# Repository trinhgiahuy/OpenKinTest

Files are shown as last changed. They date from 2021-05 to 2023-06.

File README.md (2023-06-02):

## Paper: **Surrogate Modelling for Oxygen Uptake Prediction Using LSTM Neural Network**

The article can be accessed through [mdpi](https://www.mdpi.com/1424-8220/23/4/2249)

## Test command 

```sh
rosrun vectornav vn200_node _serial_port:=/dev/ttyAMA0 _target_baud:=460800 _binary_data_output_port:=2 _binary_ins_data_output_rate:=400
gdb rosrun vectornav vn200_node _serial_port:=/dev/ttyAMA0 _target_baud:=460800 _binary_data_output_port:=2 _binary_ins_data_output_rate:=400
rostopic echo /vectornav/imugps
rostopic hz /vectornav/imugps
rostopic info /vectornav/imugps
ps aux
sudo killall python
sudo killall screen
sudo killall tee
rostopic echo --filter=m.header.seq%200==0 /vectornav/imugps

```
## Source code for devices measuring in the campaign

## TC219 CPU info

```
Device name	HTC219-720-SPC
Full device name	HTC219-720-SPC.ad.tuni.fi
Processor	Intel(R) Core(TM) i7-6700 CPU @ 3.40GHz   3.41 GHz
Installed RAM	32,0 GB
Device ID	bbbf3aca-47cd-4ad8-9fd0-ad23414388c6
Product ID	00329-00000-00003-AA689
System type	64-bit operating system, x64-based processor
Pen and touch	No pen or touch input is available for this display
```

# Usage

## Matlab instruction

Test repo for matab: `D:\(...BackupDdrive)\(..RA)\....PAVEL\MATLAB-APP\test`

- In matlab folder, create folder name ${subjectID}_out, for example `O1_out`
- The directory should include these files:
  * 2022-XX-XX-XX-XX-XX_s.txt (**sliced** ID's gaitpod file)
  * OXYGAX_marker_XXXX_s.txt(**sliced** ID'oxygen file)
  * `run.m` executable file run the everything
  * `features_OK.m`
  * `velSeg.m`
  * `input_features.m`
  * `trainingPartitions.m`
  
- At the begging `run.mat`, change subjectID and change `sortedInputFeatures` to true if want output input features in ordet (false by default) and run the file
- After about 5 mins it will produce input feature file

This section describes the basic usage of the device

## Connecting the devices
* The Xsens IMU units are currently connected through the USB ports and should be connected before powering the device.
* GPS is connected to the UART pins. The device is enumerated as /dev/ttyAMA0 on RPi and /dev/ttyS4 on minnowboard and uses 57600 baud. This all is configured in the ROS launch files.
* It is recommended that the ethernet cable is plugged to a router which will assign an IP address to the device (unless using 3G), currently the OS has issues if you switch to a different router while the device is powered?
* The device gets time from internet, so logs are dated to 1970 or some other wrong time if no internet connection has been available before starting measurements

## Powering
* The device is powered by the powerbank from the USB connector. The runtime with this seems to be around 3-4 h for RPi and 2,5 h for minnowboard.

## Measurements
* The measurement mode is activated in the boot
* Primary led will flash when time is corrected from interney
* The device will start recording as soon as it loses internet connectivity
* It might take a few minutes to start the measurements, if there are errors with gps or imu. Device will try again until everything works.
* Primary led will flash when making IMU alignment, so IMU should be stationary that time and a bit after.
* It seems, the IMU wont start if it has been stationary for some time (MTw wired), so light shake might be needed before use.
* When recording, primary led will be lit.
* Recording will be stopped once the internet connectivity is restored.
* After being stopped, the files will be uploaded to Google Drive (tutopenkin@gmail.com)

## Shutting down
* The power switch on top can be flipped to give shutdown commands to the unit.
* After flipping the switch and waiting some seconds, the USB cable powering the device can be unplugged.

# Connecting to the device
Standard SSH conenction can be made to the device with ssh:

    ssh ubuntu@[IP]
    Password: ubuntu

For RPi with kinetic user: pi, password: raspberry
For minnowboard user: openkin, password: openkin

# Libraries utilized

ROS Driver for XSens MT/MTi/MTi-G devices.

See: http://ros.org/wiki/ethzasl_xsens_driver

ROS driver for ublox

See: https://github.com/KumarRobotics/ublox

Pozyx Arduino library

See: https://github.com/pozyxLabs/Pozyx-Arduino-library

All are added as subtrees to this repo, so updates can be fetched with commands (from git root):

```
git subtree pull --prefix nodes/ublox https://github.com/KumarRobotics/ublox.git master --squash
```
,

```
git subtree pull --prefix nodes/ethzasl_xsens_driver https://github.com/ethz-asl/ethzasl_xsens_driver.git master --squash
```
and
```
git subtree pull --prefix nodes/pozyx/include/Pozyx-custom-library/ https://github.com/pozyxLabs/Pozyx-Arduino-library.git master --squash
cd nodes/pozyx/ínclude
patch -p0 < pozyx-arduino-to-linux.patch
```

# Motion Fusion

http://msthub.ain.rd.tut.fi/mobilemachines/motion_fusion/blob/master/src/KalmanImu.py

# Script startup
The measurements are started by running ~/openkin/start_script.sh, which in turn calls the main script at ~/openkin/measurement.sh using locks.
The script now starts from /etc/rc.local, with lockfile at /home/ubuntu/measurement.lock and as user ubuntu (or pi or openkin).

# Old documentation...
... can be found in Google Docs with the tutopenkin@gmail.com -account.

# For latest documentation, please look at [doc/](doc/)

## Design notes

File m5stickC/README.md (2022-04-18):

[Arduino IDE environment - M5StickC Plus](https://docs.m5stack.com/en/quick_start/m5stickc_plus/arduino)

[Example demo](https://www.brianmoreau.com/projects/M5StickC_Demo/M5StickC_Demo.php)

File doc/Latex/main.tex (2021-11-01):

\documentclass{report}
\usepackage[utf8]{inputenc}
\usepackage{pdfpages}
\usepackage{hyperref}
\usepackage{graphicx}
\usepackage{float}

\title{Datalogger Documentation}
\graphicspath{{./Images/}}
\author{Huy Trinh }
\date{August 2021}

\begin{document}

\begin{titlepage}
\maketitle
\end{titlepage}

\section{Overview}

The datalogger configuration includes\\
\\\textbf{Raspberry Pi 3 Model B + Vectornav VN200}
\\
\\These can be found through these links
\begin{enumerate}
    \item RPi: \url{https://www.raspberrypi.org/products/raspberry-pi-3-model-b/}
    \item VectorNav
    \begin{enumerate}
        \item[2.1] Quick start manual:\url{https://www.vectornav.com/docs/default-source/datasheets/vn-200-datasheet-rev2.pdf?sfvrsn=e1a7b2a0_10}
        \item[2.2] Complete manual page: \url{https://2w6vmg3m8cv83pn80b2dfi9f-wpengine.netdna-ssl.com/wp-content/uploads/assets/1/7/VN200UserManual_UM004_080514.pdf}
    \end{enumerate}
    \item PoEHat: \url{https://www.raspberrypi.org/products/poe-hat/}
\end{enumerate}
The GNSS/VectorNav connects to the mainboard (Raspberry Pi) through UART serial connection.

\section{Hardware}
\subsection{Circuit}
The USB power input is connected to 5V pins along with GNSS power. GNSS data is connected to UART pins. Power switch is connected between GPIO18 (BCM) and ground, pullup enabled in software. Primary LED (blue) is connected to GPIO24 (BCM), secondary LED (green) is connected to GPIO25 (BCM) and tertiary LED (red) is connected to GPIO10 (BCM). All the LEDs are driven with MOSFETs/NPN-transistors.More detail can found at: \url{https://tinyurl.com/ygbxmabs} 
\begin{figure}[H]
    \centering
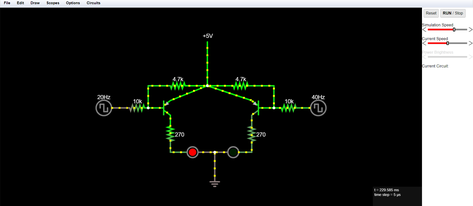
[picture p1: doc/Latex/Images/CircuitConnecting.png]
    
    \caption{CircuitConnecting}
    \label{fig:my_label}
\end{figure}

\subsection{SD Card}
The SD should be 64 GB of space in order to store as much as possible the data collected from the datalogger.\textbf{Remember:} The origin image of the datalogger that we fetch is 32 GB, thus the minimum 32 GB space of SD card is required  
\subsection{USB 3G Modem}
Originally Huawei E160E was used, which works well with 3G speeds. Currently Huawei E3372 4G modem is used (Hi-Link mode). Any modem, which has support on Linux probably can be made to work, some modems can draw more power though, especially LTE modems. On RPi \textbf{max\_usb\_current}=1 setting can be used in \textit{/boot/config.txt}.
\section{Software}
Software can be foud in \url{} repository. Datalogger has accessed to the repo
\subsection{Raspverry Pi Specific}
The raspberry Pi run with operating system Raspbian Jessie with ROS Kinetic Kame, built from source with these instruction \url{http://wiki.ros.org/kinetic/Installation/Source}. More detailed instruction can be found below
\\
\\\textbf{shutdown\_flip.py}:
\\Listens to specific GPIO pin and initiates the shutdown sequence on switch flip
\\
\\\textbf{led-pin.py}:
\\Listen to linux signals USR1 and USR2 to turn led on and off.
\\RPi has one or two pins for HW PWM, but apparently no sysfs interface by default
\\
\\\textbf{led-linuxgpio.sh}:
\\Mainly control the led. Currently, the script is called in measurement script with inverse mode (mode 4). The inverse mode simply reverse the value of variable ON/OFF in its script.
\\
\\\textbf{measurement.sh}
\\The script manage the running nodes nad check if the Internet connection. When the logger is offline, it starts the nodes and logging. When the internet connection is established, the logger uploads the measured data into github/gitlab account.
\\
\\ There are few setting at the beginning of the script, like log files and Leds connected. There are few functions for controlling Leds, currently, we used the led-linuxgpio.sh with inverse mode (mode 4).
\\
\\Function check3G check whether there is \textit{Huawei E160E data stick} is connected, and tries to connect to the internet using \textit{sakis3g-script} (in our case there is not necessary since we are using the \textit{E3372 dongle}).
\\
\\When online for the first time, time is corrected using ntpdate from time1.mikes.fi ntp server and led is blinked fast. When internet is established, it will upload the data into the github/gitlab repository over SSH.
\\
\\\textbf{start\_script.sh}:
\\Start the \textbf{measurement.sh} script using flock. Flockfiles prevent multiple instances of measurement.sh from running at the same time. 

\subsection{Robotic Operating System ROS}
ROS is an open-source, meta-operating system for your robot that providing you with services including hardware abstraction, low-level device control, implementation of commonly-used functionality, message-passing between processes, and package management. It also provides tools and libraries for obtaining, building, writing, and running code across multiple computers. ROS distribution is a versioned set of ROS packages. In our case we use the \textbf{ROS Kinetic Kame} distro.
\subsubsection{VectorNav node}
Highly modified version of \url{https://github.com/dawonn/vectornav}. The data from INS is read over UART at maximum baudrate and then the data is published in custom ROS message (imugps) including necessary fields. THe node also automatically tries to change the baudrate if is not correct. It also includes some configuration for the INS like GPS antenna offset and magnetometer velocity threshold. Also the LED control for turining the LED solid when the GPS fix is acquired.
\subsubsection{ROS Conceptual Terms}
\subsubsection{catkin workspace}
catkin is official build system that combines CMake macros and Python script to provide some functionality on top of  CMake's normal workflow. Catkin is more conventional than \textit{rosbuild} in packages distribution, cross-compiling support and portability. 
\subsubsection{nodes}
Nodes are processes that perform computation. For example, one node controls a laser range-finder, one node controls the wheel motors, one node performs localization, one node performs path planning, one Node provides a graphical view of the system, and so on. A ROS node is written with the use of a ROS client library, such as roscpp or rospy.
\subsubsection{rospy}
rospy is a pure Python client library for ROS. The rospy client API enables Python programmers to quickly interface with ROS Topics, Services, and Parameters.
\subsubsection{topics}
Topics are named buses over which nodes exchange messages. Topics have anonymous publish/subscribe semantics, which decouples the production of information from its consumption. In general, nodes are not aware of who they are communicating with. Instead, nodes that are interested in data subscribe to the relevant topic; nodes that generate data publish to the relevant topic. There can be multiple publishers and subscribers to a topic.
\\We can check our available topic with command \textit{\$ rostopic list} and display messages published to /topic\_name by \textit{\$ rostopic echo /topic\_name}
\subsubsection{messages}
Nodes communicate with each other by publishing the \textbf{messages} to topics. A message is a simple data structure comprise the specific fields.
\begin{itemize}
    \item \textbf{msg files}: are simple text files for specifying the data structure of a message. These files are stored in the msg subdirectory of a package. For more information about these files, including a type specification, see the \textit{\href{https://wiki.ros.org/msg}{\underline{msg format}}}.
    \item \textbf{msg types}: are understand of ROS \textit{\href{https://wiki.ros.org/Names}{\underline{naming}}} convention: the name of package + / + name of .msg file. For instance, the \textit{std\_msgs/msg/String.msg} has the message type \textit{std\_msgs/String}
    \item \textbf{building}: ROS \textit{\href{http://wiki.ros.org/Client\%20Libraries} {\underline{Client Libraries}}} implement a message generator that translate .msg file into source code.
    The generator must be invoked from your build script by adding the line
    \textbf{\textit{rosbuild\_genmsg()}} to your
    \href{https://wiki.ros.org/action/show/rosbuild/CMakeLists?action=show&redirect=CMakeLists}{\underline{CMakeList.txt}}
    \item \textbf{header}: A msg may include a special message type called 'Header', which include some common metadata field such as timestamp and frame ID.
    \begin{figure}[H]
        \centering
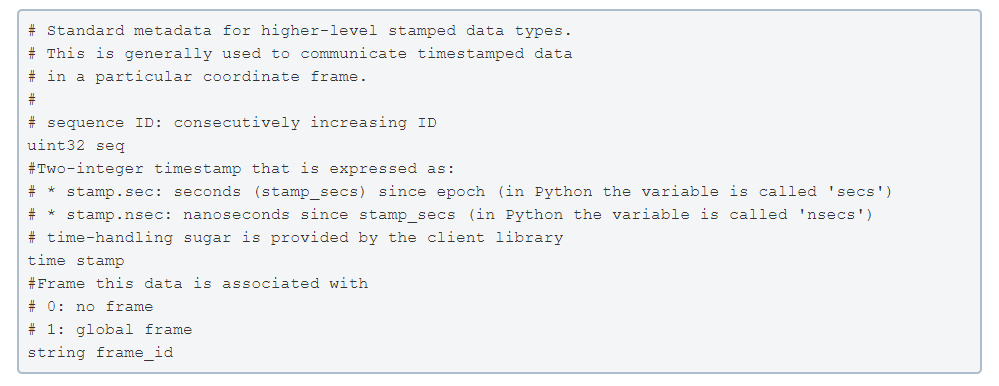
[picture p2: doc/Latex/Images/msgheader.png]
        
        \caption{Message Header}
        \label{fig:my_label}
    \end{figure}
\end{itemize}
\subsubsection{bags}
Bags are a format for saving and playing back ROS message data. Bags are an important mechanism for storing data, such as sensor data, that can be difficult to collect but is necessary for developing and testing algorithms.
\subsubsection{package}
\href{http://wiki.ros.org/Packages}{Packages} might contain ROS nodes, ROS-independent library, a dataset, configuration files, a third-party software. Packages are created by hand or with tools like \textbf{catkin\_create\_pkg}. ROS package is a directory desended from \textit{ROS\_PACKAGE\_PATH} in \textit{\href{http://wiki.ros.org/ROS/EnvironmentVariables}{\underline{ROS Environment variable}}} that has a \href{http://wiki.ros.org/Manifest}{\textit{package.xml}} file in it.\\
ROS packages commonly contain the following strucutes.
\begin{itemize} 
    \item \textit{include/package\_name}: C++ incude header (make sure it export in CMakeLists.txt) 
    \item \textit{msg}/: folder contain Message(msg) types
    \item \textit{src/package\_name/}: source file, especially Python source that are exported to other packages
    
    %Do not know why if we use \textit here will cause error of `undefined control sequence` but change to \emph get rid of it
    \item \emph{scripts/}: executabe scripts
    \item \emph{CMakeList.txt}: CMake build file
    \item \emph{package.xml}: Package
    \underline{\href{http://wiki.ros.org/catkin/CMakeLists.txt}{catkin/CMakeLists.txt}}
\end{itemize}
There are few tools that help to manage the packages
\begin{itemize}
    \item \textit{rospack}: find and retrieve information about packet
    \item \textit{catkin\_create\_package}: create a new package
    \item \textit{catkin\_make}: build a workspace of package
    \item \textit{rosdep}: install system dependencies of a package
\end{itemize}
\subsubsection{catkin\_make}
A convenience tool for buidling code in workspace. Here we use\\
\textbf{\emph{\$ cd \~/catkin\_ws}}\\
\textbf{\emph{\$ catkin\_make}}\\
to compile and build our workspace. After running \emph{\textbf{catkin\_make}} we have 2 folder \emph{build} and \emph{devel} in our root of catkin workspace. The \emph{build} folder is where \emph{cmake} and \emph{make} are invoke, and the devel folder contains any generated files and targets, plus setup *.sh file so that you can use it like it is installed.

\subsubsection{package.xml}
A \textbf{package manifest} XML file that must be included with any catkin-compliant package's root folder that defines that package's properties such as package name, version number, author, maintainers and dependencies on other catkin package.\\
Some required tags include\\
\begin{itemize}
% Why <> cannot be compiled?
    \item \textit{name}: <name> of package
    \item \emph{<version>}: version of package
    \item \emph{<description>}: description of package content
    \item \emph{<maintainer>}: the name of person(s) that is/are maintaining the package
    \item \emph{<license>}: software license(s) (e.g GPL,BSD,ASL) under which code is release 
\end{itemize}

\subsection{Installing software}
First, operating system should be installed, for example (L)Ubuntu 16.04 minimal. Instructions can be found on Ubuntu website, for example: \url{https://help.ubuntu.com/community/Lubuntu/Documentation/MinimalInstall}. 
\\
Instructions for installing ROS can be found in \url{http://wiki.ros.org/kinetic/Installation/}.\\
Brief list of commands:
*adjust usernames etc. according to the local user, here openkin or pi*\\
\\
\# For raspbian jessie source installation: \# enough swap for build to succeed \\
\\
sudo fallocate -l 2G /var/swap2 \\ 
\\
sudo chmod 600 /var/swap2 \\
\\
sudo swapon /var/swap2 \\
\\
sudo sh -c 'echo "deb http://packages.ros.org/ros/ubuntu \$(lsb\_release -sc) main" > /etc/apt/sources.list.d/ros-latest.list' \\
\\
sudo apt-key adv --keyserver 'hkp://keyserver.ubuntu.com:80' --recv-keyC1CF6E31E6BADE8868B172B4F42ED6FBAB17C654 \\
\\
sudo apt-key del 421C365BD9FF1F717815A3895523BAEEB01FA116 \\
\\
sudo apt-get install python-rosdep python-rosinstall-generator python-wstool python-rosinstall build-essential git libgps-dev i2c-tools libi2c-dev \\
\\
sudo rosdep init \\
\\
rosdep uodate \\
\\
cd \\ 
\\
mkdir ros\_catkin\_ws \\
\\
cd ros\_catkin\_ws \\
\\
rosinstall\_generator ros\_comm --rosdistro kinetic --deps --wet-only --tar > kinetic-ros\_comm-wet.rosinstall \\
\\
roslocate info common\_msgs --distro=kinetic >> kinetic-ros\_comm-wet.rosinstall \\
\\
roslocate info tf --distro=kinetic >> kinetic-ros\_comm-wet.rosinstall \\
\\
roslocate info tf2 --distro=kinetic >> kinetic-ros\_comm-wet.rosinstall \\
\\
roslocate info diagnostic\_updater --distro=kinetic >> kinetic-ros\_comm-wet.rosinstall \\
\\
roslocate info actionlib --distro=kinetic >> kinetic-ros\_comm-wet.rosinstall \\
\\
roslocate info python\_orocos\_kdl --distro=kinetic >> kinetic-ros\_comm-wet.rosinstall \\
\\
roslocate info bondcpp --distro=kinetic >> kinetic-ros\_comm-wet.rosinstall \\
\\
nano kinetic-ros\_comm-wet.rosinstall \\
\\
\textbf{\emph{add to the end of file: - git: local-name:}} \\
\\
rosbag\_migration\_rule uri: \\
https://github.com/ros/rosbag\_migration\_rule.git\\
version: master \\
\*
\\
roslocate info pluginlib --distro=kinetic >> kinetic-ros\_comm-wet.rosinstall \\
\\
roslocate info angles --distro=kinetic >> kinetic-ros\_comm-wet.rosinstall \\
\\
roslocate info class\_loader --distro=kinetic >> kinetic-ros\_comm-wet.rosinstall \\
\\
wstool init -j4 src kinetic-ros\_comm-wet.rosinstall \\
\\
(sudo cp /usr/share/cmake-3.0/Modules/FindEigen3.cmake /usr/share/cmake-3.6/Modules/) \\
\\
rosdep install --from-paths src --ignore-src --rosdistro kinetic -y \\
\\
sudo mkdir -p /opt/ros/kinetic \\
\\
sudo chmod -R 777 /opt/ros \\
\\
sudo chown -R pi:pi /opt/ros \\
\\
./src/catkin/bin/catkin\_make\_isolated --install --install-space /opt/ros/kinetic -DCMAKE\_BUILD\_TYPE=Release \\
\\
cd\\
\\
\# Normal ubuntu, skip if from source\\
\\
The complete image of Ubuntu 16-04 with ROS kinetic already installed for raspberry pi 3 can be found at \url{https://ubiquity-pi-image.sfo2.cdn.digitaloceanspaces.com/2020-11-07-ubiquity-xenial-lxde-raspberry-pi.img.xz}\\
\\
sudo sh -c 'echo "deb http://packages.ros.org/ros/ubuntu \$(lsb\_release -sc) main" > /etc/apt/sources.list.d/ros-latest.list' 
\\
sudo apt-key adv --keyserver 'hkp://keyserver.ubuntu.com:80' --recv-keyC1CF6E31E6BADE8868B172B4F42ED6FBAB17C654 \\
\\
sudo apt-key del 421C365BD9FF1F717815A3895523BAEEB01FA116 \\
\\
sudo apt-get update\\
\\
rosdep update\\
\\
source ~/.bashrc\\
\\
sudo apt-get install libgps-dev libi2c-dev ntpdate\\
\\
sudo apt-get upgrade\\
\\
\\
\# Same for here\\
\\
% Not need to init catkin workspace anymore
catkin\_make\\
\\
source devel/setup.bash\\
\\
\textbf{\#If you start from here with fetching from the complete datalogger image}\\
\\
cd catkin\_ws/src\\
\\
ln -s /home/openkin/openkin/nodes/ascii\_logger/ascii\_logger\\
\\
ln -s /home/openkin/NewGaitMaven/nodes/vectornav vectornav \\
\\
\# for rpi \\
\\cd\\
\\
wget https://github.com/joan2937/pigpio/archive/master.zip\\
\\
unzip master.zip \\
\\
cd pigpio-master \\
\\
make -j4 \\
\\
sudo make install\\
\\
cd ~/catkin\_ws \\
\\
catkin\_make\\
\\
sudo visudo \\
\\
\textbf{*add line at the end: “openkin ALL=(ALL:ALL) NOPASSWD: ALL”*}\\
\\
sudo apt-get install screen ppp usb-modeswitch\\
\\
\textbf{\#if using E160E or similar }\\
\\
wget http://www.sakis3g.com/downloads/sakis3g.tar.gz\\
\\
tar -xzvf sakis3g.tar.gz\\
\\
sudo mv sakis3g /usr/bin/sakis3g \\
\\
sudo chown root:root /usr/bin/sakis3g\\
\\
sudo chmod +x /usr/bin/sakis3g \\
\\
\textbf{*if e3372 doesn’t work out of the box*}\\
\\
\textbf{*remove old usb\_modeswitch*}\\
\\
\textbf{*install tcl, libusb-1.0-0-dev etc.*}\\
\\
\textbf{*download latest usb\_modeswitch http://www.draisberghof.de/usb\_modeswitch/\#install*}\\
\\
\textbf{*sudo make install*}\\
\\
\\
\\
\textbf{Here we start to install git lfs for data storage}
% Add install golang and gitlfs
\\
\\
\\
cd \~/openkin/NewGaitMaven/linux-shutdown\\
\\
make\\
\\
\\
\\
% Enable automatic measurement
sudo nano /etc/rc.local\\
\\
\textbf{*add line before exit 0:}\\
\textit{“su -c “/home/openkin/NewGaitMaven/start\_script.sh” openkin}\\
\\
\textbf{*for rpi add shutdown\_flip*}\\
\\
\textbf{*check permissions for serial device, pi: /boot/cmdline.txt: remove serial terminal*}\\
\\
\textbf{*add source’s to .bashrc*}\\
\\
\textbf{*check usernames and folders in measurement.sh*}\\
\\
\\
\\
\# \textbf{For mtmanager}\\
\\
sudo apt-get install libqtopengl5 \\
\\
\textbf{*download mtmanager, extract, symlink to /usr/local/bin *}\\
\\
\subsection{3D Printed Cases}
Models can be found in 3D folder. They can be redesigned with SolidWork/FreeCad. FreeCad can be download for free. However, SolidWork require license from university and can be installed from IT-helpdesk.
\textbf{Some information and settings for printers} \\
Get start by running the script 
C:$\backslash$Minifactory$\backslash$Config$\backslash$first\_time\_config.bat.
Then press any key to continue\\
\\
Open Minifactory\\
\textbf{Step 1}: Start connect Z-calibration\\
\textbf{Step 2}: Run the nozzle up/down by pressing the arrow button until the paper slightly rubs between the nozzle and the print bed. Confirm height with “Ready” button. The height should be around 150cm\\
In manual control tab, uncheck the flowrate, bed temperature, extruder 1, extruder 2,. We mostly use extruder 1 for printing, the temperature is around 200 degree celsius.  

In object placement, add object and rotate it that its suitable (not need to much support )
In slicer tab, choose Slicer as Slic 3r or CuraEngine (prefered). If CuraEngine, the quality should be 0.2 mm and support everywhere.. The Filament setting is PLA for both extruder.

The preview tab can show each layer in real-time printing. Also, it shows the estimated print time, layer counts. Finally press Start Print.

\section{Usage}
\subsection{VectorNav}
The datalogger is off, if light is not on. The 4G modem should also be connected to the USB port before turning the logger on. The logger can be turn on by pressing the power button on the battery, inserting the battery to the case and connecting USB-cable to the battery. The logger will turn on and off the red and green leds when powering up respectively. When the logger acquire the internet connection, the green led is turned on. When the logger is synchronizing github/gitlab server, the green led is flashing\\
\\
When the logger has been on for a while and the green led is on, the logger is ready for starting measurement. The measurement can be started by disconnecting the 4G modem. 
The green led goes off and after a while, the red should start blinking if the VectorNav does not have fix, or if everything seem to be fine, the red led is turned on. It is still recommend to wait for GPS to acquire better stability, but the recording is running.\\
\\
When measurement are done, the recording can be stopped by reconnecting the 4G modem. The red led shuts off and the green led starts to blink as files are upload to github/gitlab. When the upload is done, the green led stabilize.\\
\\
The logger can be turn off by turning the power/shutdown switch off, and waiting for 10-30 seconds for all lights to go off. When logger is off, the USB power cable can be disconnected with care, and battery removed.\\
\\
Note: JYU version has reverse switch direction compared to other loggers, on is out, off is towards the antenna.

\section{SSH access}
The datalogger have SSH server running, and they can be accessed by connecting the datalogger via ethernet. The network should have DHCP to give IP address for the datalogger. For example internet sharing on Mac and Linux can be used for connecting the datalogger straight to the computer.\\
\\
The IP of the datalogger can possibly found using \textit{nmap}: \textit{nmap -sn 192.168.2.1-255} where IP range is subnet defined for network. The SSH connection can be mad with command \textit{ssh pi$@$192.168.2.3} where IP is the IP of the datalogger, and pi is the username.\\
\\
Username for Raspberry Pi based datalogger is pi. Password is raspberry for pi and openkin for openkin.\\
\\
\end{document}

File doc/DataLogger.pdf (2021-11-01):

# Datalogger Documentation

Huy Trinh

August 2021

## 0.1 Overview

The datalogger configuration includes

Raspberry Pi 3 Model B + Vectornav VN200

These can be found through these links

1. RPi: https://www.raspberrypi.org/products/raspberry-pi-3-model-b/
2. VectorNav

2.1 Quick start manual:https://www.vectornav.com/docs/default-source/datasheets/vn-200-datasheet-rev2.pdf?sfvrsn=e1a7b2a0_10 (https://www.vectornav.com/docs/default-source/datasheets/vn-200-datasheet-rev2.pdf?sfvrsn=e1a7b2a0_10)

2.2 Complete manual page: https://2w6vmg3m8cv83pn80b2dfi9f-wpengine.netdna-ssl.com/wp-content/uploads/assets/1/7/VN200UserManual_UM004_080514.pdf (https://2w6vmg3m8cv83pn80b2dfi9f-wpengine.netdna-ssl.com/wp-content/uploads/assets/1/7/VN200UserManual_UM004_080514.pdf)

3. PoEHat: https://www.raspberrypi.org/products/poe-hat/

The GNSS/VectorNav connects to the mainboard (Raspberry Pi) through UART serial connection.

## 0.2 Hardware

### 0.2.1 Circuit

The USB power input is connected to 5V pins along with GNSS power. GNSS data is connected to UART pins. Power switch is connected between GPIO18 (BCM) and ground, pullup enabled in software. Primary LED (blue) is connected to GPIO24 (BCM), secondary LED (green) is connected to GPIO25 (BCM) and tertiary LED (red) is connected to GPIO10 (BCM). All the LEDs are driven with MOSFETs/NPN-transistors.More detail can found at: https: //tinyurl.com/ygbxmabs

1

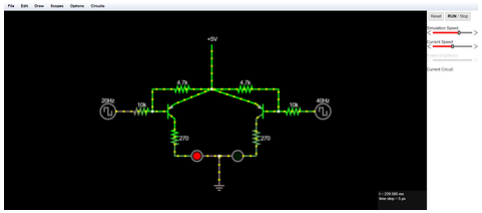
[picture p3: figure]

Figure 1: CircuitConnecting

### 0.2.2 SD Card

The SD should be 64 GB of space in order to store as much as possible the data collected from the datalogger.Remember: The origin image of the datalogger that we fetch is 32 GB, thus the minimum 32 GB space of SD card is required

### 0.2.3 USB 3G Modem

Originally Huawei E160E was used, which works well with 3G speeds. Currently Huawei E3372 4G modem is used (Hi-Link mode). Any modem, which has support on Linux probably can be made to work, some modems can draw more power though, especially LTE modems. On RPi max usb current=1 setting can be used in /boot/config.txt.

## 0.3 Software

Software can be foud in repository. Datalogger has accessed to the repo

### 0.3.1 Raspverry Pi Specific

The raspberry Pi run with operating system Raspbian Jessie with ROS Kinetic Kame, built from source with these instruction http://wiki.ros.org/kinetic/Installation/Source. (http://wiki.ros.org/kinetic/Installation/Source) More detailed instruction can be found below

shutdown flip.py:
Listens to specific GPIO pin and initiates the shutdown sequence on switch flip

led-pin.py:
Listen to linux signals USR1 and USR2 to turn led on and off.

2

RPi has one or two pins for HW PWM, but apparently no sysfs interface by default

led-linuxgpio.sh:
Mainly control the led. Currently, the script is called in measurement script with inverse mode (mode 4). The inverse mode simply reverse the value of variable ON/OFF in its script.

measurement.sh
The script manage the running nodes nad check if the Internet connection. When the logger is offline, it starts the nodes and logging. When the internet connection is established, the logger uploads the measured data into github/gitlab account.

There are few setting at the beginning of the script, like log files and Leds connected. There are few functions for controlling Leds, currently, we used the led-linuxgpio.sh with inverse mode (mode 4).

Function check3G check whether there is Huawei E160E data stick is connected, and tries to connect to the internet using sakis3g-script (in our case there is not necessary since we are using the E3372 dongle).

When online for the first time, time is corrected using ntpdate from time1.mikes.fi ntp server and led is blinked fast. When internet is established, it will upload the data into the github/gitlab repository over SSH.

start script.sh:
Start the measurement.sh script using flock. Flockfiles prevent multiple instances of measurement.sh from running at the same time.

### 0.3.2 Robotic Operating System ROS

ROS is an open-source, meta-operating system for your robot that providing you with services including hardware abstraction, low-level device control, implementation of commonly-used functionality, message-passing between processes, and package management. It also provides tools and libraries for obtaining, building, writing, and running code across multiple computers. ROS distribution is a versioned set of ROS packages. In our case we use the ROS Kinetic Kame distro.

VectorNav node

Highly modified version of https://github.com/dawonn/vectornav. The data from INS is read over UART at maximum baudrate and then the data is published in custom ROS message (imugps) including necessary fields. THe node also automatically tries to change the baudrate if is not correct. It also includes

3

some configuration for the INS like GPS antenna offset and magnetometer velocity threshold. Also the LED control for turining the LED solid when the GPS fix is acquired.

ROS Conceptual Terms

catkin workspace

catkin is official build system that combines CMake macros and Python script to provide some functionality on top of CMake’s normal workflow. Catkin is more conventional than rosbuild in packages distribution, cross-compiling support and portability.

nodes

Nodes are processes that perform computation. For example, one node controls a laser range-finder, one node controls the wheel motors, one node performs localization, one node performs path planning, one Node provides a graphical view of the system, and so on. A ROS node is written with the use of a ROS client library, such as roscpp or rospy.

rospy

rospy is a pure Python client library for ROS. The rospy client API enables Python programmers to quickly interface with ROS Topics, Services, and Parameters.

topics

Topics are named buses over which nodes exchange messages. Topics have anonymous publish/subscribe semantics, which decouples the production of information from its consumption. In general, nodes are not aware of who they are communicating with. Instead, nodes that are interested in data subscribe to the relevant topic; nodes that generate data publish to the relevant topic. There can be multiple publishers and subscribers to a topic.
We can check our available topic with command $ rostopic list and display messages published to /topic name by $ rostopic echo /topic name

messages

Nodes communicate with each other by publishing the messages to topics. A message is a simple data structure comprise the specific fields.

- msg files: are simple text files for specifying the data structure of a message. These files are stored in the msg subdirectory of a package. For more information about these files, including a type specification, see the msg format. (https://wiki.ros.org/msg)

4

- msg types: are understand of ROS naming (https://wiki.ros.org/Names) convention: the name of package + / + name of .msg file. For instance, the std msgs/msg/String.msg has the message type std msgs/String
- building: ROS Client Libraries (http://wiki.ros.org/Client%20Libraries) implement a message generator that translate .msg file into source code. The generator must be invoked from your build script by adding the line rosbuild genmsg() to your CMakeList.txt (https://wiki.ros.org/action/show/rosbuild/CMakeLists?action=show&redirect=CMakeLists)
- header: A msg may include a special message type called ’Header’, which include some common metadata field such as timestamp and frame ID.


Figure 2: Message Header

bags

Bags are a format for saving and playing back ROS message data. Bags are an important mechanism for storing data, such as sensor data, that can be difficult to collect but is necessary for developing and testing algorithms.

package

Packages (http://wiki.ros.org/Packages) might contain ROS nodes, ROS-independent library, a dataset, configuration files, a third-party software. Packages are created by hand or with tools like catkin create pkg. ROS package is a directory desended from ROS PACKAGE PATH in ROS Environment variable (http://wiki.ros.org/ROS/EnvironmentVariables) that has a package.xml (http://wiki.ros.org/Manifest) file in it.
ROS packages commonly contain the following strucutes.
- include/package name: C++ incude header (make sure it export in CMake-Lists.txt)
- msg/: folder contain Message(msg) types
- src/package name/ : source file, especially Python source that are exported to other packages

5

- scripts/ : executabe scripts
- CMakeList.txt: CMake build file
- package.xml: Package catkin/CMakeLists.txt (http://wiki.ros.org/catkin/CMakeLists.txt)

There are few tools that help to manage the packages

- rospack: find and retrieve information about packet
- catkin create package: create a new package
- catkin make: build a workspace of package
- rosdep: install system dependencies of a package

catkin make

A convenience tool for buidling code in workspace. Here we use
$ cd ˜/catkin ws
$ catkin make
to compile and build our workspace. After running catkin make we have 2 folder build and devel in our root of catkin workspace. The build folder is where cmake and make are invoke, and the devel folder contains any generated files and targets, plus setup *.sh file so that you can use it like it is installed.

package.xml

A package manifest XML file that must be included with any catkin-compliant package’s root folder that defines that package’s properties such as package name, version number, author, maintainers and dependencies on other catkin package.
Some required tags include
- name: ¡name¿ of package
- ¡version¿: version of package
- ¡description¿: description of package content
- ¡maintainer¿: the name of person(s) that is/are maintaining the package
- ¡license¿: software license(s) (e.g GPL,BSD,ASL) under which code is release

6

### 0.3.3 Installing software

First, operating system should be installed, for example (L)Ubuntu 16.04 minimal. Instructions can be found on Ubuntu website, for example: https: //help.ubuntu.com/community/Lubuntu/Documentation/MinimalInstall. Instructions for installing ROS can be found in http://wiki.ros.org/kinetic/Installation/. (http://wiki.ros.org/kinetic/Installation/)
Brief list of commands: *adjust usernames etc. according to the local user, here openkin or pi*

# For raspbian jessie source installation: # enough swap for build to succeed

sudo fallocate -l 2G /var/swap2

sudo chmod 600 /var/swap2

sudo swapon /var/swap2

sudo sh -c ’echo ”deb http://packages.ros.org/ros/ubuntu $(lsb release -sc) main”
¿ /etc/apt/sources.list.d/ros-latest.list’

sudo apt-key adv –keyserver ’hkp://keyserver.ubuntu.com:80’ –recv-keyC1CF6E31E6BADE8868B172B4F42ED6FBAB17C654

sudo apt-key del 421C365BD9FF1F717815A3895523BAEEB01FA116

sudo apt-get install python-rosdep python-rosinstall-generator python-wstool python-rosinstall build-essential git libgps-dev i2c-tools libi2c-dev

sudo rosdep init

rosdep uodate

cd

mkdir ros catkin ws

cd ros catkin ws

rosinstall generator ros comm –rosdistro kinetic –deps –wet-only –tar ¿ kinetic-ros comm-wet.rosinstall

roslocate info common msgs –distro=kinetic ¿¿ kinetic-ros comm-wet.rosinstall

roslocate info tf –distro=kinetic ¿¿ kinetic-ros comm-wet.rosinstall

roslocate info tf2 –distro=kinetic ¿¿ kinetic-ros comm-wet.rosinstall

7

roslocate info diagnostic updater –distro=kinetic ¿¿ kinetic-ros comm-wet.rosinstall

roslocate info actionlib –distro=kinetic ¿¿ kinetic-ros comm-wet.rosinstall

roslocate info python orocos kdl –distro=kinetic ¿¿ kinetic-ros comm-wet.rosinstall

roslocate info bondcpp –distro=kinetic ¿¿ kinetic-ros comm-wet.rosinstall

nano kinetic-ros comm-wet.rosinstall

add to the end of file: - git: local-name:

rosbag migration rule uri: https://github.com/ros/rosbag migration rule.git
version: master

roslocate info pluginlib –distro=kinetic ¿¿ kinetic-ros comm-wet.rosinstall

roslocate info angles –distro=kinetic ¿¿ kinetic-ros comm-wet.rosinstall

roslocate info class loader –distro=kinetic ¿¿ kinetic-ros comm-wet.rosinstall

wstool init -j4 src kinetic-ros comm-wet.rosinstall

(sudo cp /usr/share/cmake-3.0/Modules/FindEigen3.cmake /usr/share/cmake-3.6/Modules/)

rosdep install –from-paths src –ignore-src –rosdistro kinetic -y

sudo mkdir -p /opt/ros/kinetic

sudo chmod -R 777 /opt/ros

sudo chown -R pi:pi /opt/ros

./src/catkin/bin/catkin make isolated –install –install-space /opt/ros/kinetic -DCMAKE BUILD TYPE=Release

cd

# Normal ubuntu, skip if from source

The complete image of Ubuntu 16-04 with ROS kinetic already installed for raspberry pi 3 can be found at https://ubiquity-pi-image.sfo2.cdn.digitaloceanspaces.com/2020-11-07-ubiquity-xenial-lxde-raspberry-pi.img.xz (https://ubiquity-pi-image.sfo2.cdn.digitaloceanspaces.com/2020-11-07-ubiquity-xenial-lxde-raspberry-pi.img.xz)

8

sudo sh -c ’echo ”deb http://packages.ros.org/ros/ubuntu $(lsb release -sc) main”
¿ /etc/apt/sources.list.d/ros-latest.list’
sudo apt-key adv –keyserver ’hkp://keyserver.ubuntu.com:80’ –recv-keyC1CF6E31E6BADE8868B172B4F42ED6FBAB17C654

sudo apt-key del 421C365BD9FF1F717815A3895523BAEEB01FA116

sudo apt-get update

rosdep update

source /.bashrc

sudo apt-get install libgps-dev libi2c-dev ntpdate

sudo apt-get upgrade

# Same for here

catkin make

source devel/setup.bash

#If you start from here with fetching from the complete datalogger image

cd catkin ws/src

ln -s /home/openkin/openkin/nodes/ascii logger/ascii logger

ln -s /home/openkin/NewGaitMaven/nodes/vectornav vectornav

# for rpi

cd

wget https://github.com/joan2937/pigpio/archive/master.zip

unzip master.zip

cd pigpio-master

make -j4

sudo make install

9

cd /catkin ws

catkin make

sudo visudo

*add line at the end: “openkin ALL=(ALL:ALL) NOPASSWD: ALL”*

sudo apt-get install screen ppp usb-modeswitch

#if using E160E or similar

wget http://www.sakis3g.com/downloads/sakis3g.tar.gz

tar -xzvf sakis3g.tar.gz

sudo mv sakis3g /usr/bin/sakis3g

sudo chown root:root /usr/bin/sakis3g

sudo chmod +x /usr/bin/sakis3g

*if e3372 doesn’t work out of the box*

*remove old usb modeswitch*

*install tcl, libusb-1.0-0-dev etc.*

*download latest usb modeswitch http://www.draisberghof.de/usb modeswitch/#install*

*sudo make install*

Here we start to install git lfs for data storage

cd ˜/openkin/NewGaitMaven/linux-shutdown

make

sudo nano /etc/rc.local

10

*add line before exit 0:
“su -c “/home/openkin/NewGaitMaven/start script.sh” openkin

*for rpi add shutdown flip*

*check permissions for serial device, pi: /boot/cmdline.txt: remove serial terminal*

*add source’s to .bashrc*

*check usernames and folders in measurement.sh*

# For mtmanager

sudo apt-get install libqtopengl5

*download mtmanager, extract, symlink to /usr/local/bin *

0.3.4 3D Printed Cases

Models can be found in 3D folder. They can be redesigned with SolidWork/FreeCad. FreeCad can be download for free. However, SolidWork require license from university and can be installed from IT-helpdesk. Some information and settings for printers
Get start by running the script C:\Minifactory\Config\first time config.bat. Then press any key to continue

Open Minifactory
Step 1: Start connect Z-calibration
Step 2: Run the nozzle up/down by pressing the arrow button until the paper slightly rubs between the nozzle and the print bed. Confirm height with “Ready” button. The height should be around 150cm
In manual control tab, uncheck the flowrate, bed temperature, extruder 1, extruder 2,. We mostly use extruder 1 for printing, the temperature is around 200 degree celsius.
In object placement, add object and rotate it that its suitable (not need to much support ) In slicer tab, choose Slicer as Slic 3r or CuraEngine (prefered). If CuraEngine, the quality should be 0.2 mm and support everywhere.. The Filament setting is PLA for both extruder.
The preview tab can show each layer in real-time printing. Also, it shows the estimated print time, layer counts. Finally press Start Print.

11

## 0.4 Usage

### 0.4.1 VectorNav

The datalogger is off, if light is not on. The 4G modem should also be connected to the USB port before turning the logger on. The logger can be turn on by pressing the power button on the battery, inserting the battery to the case and connecting USB-cable to the battery. The logger will turn on and off the red and green leds when powering up respectively. When the logger acquire the internet connection, the green led is turned on. When the logger is synchronizing github/gitlab server, the green led is flashing

When the logger has been on for a while and the green led is on, the logger is ready for starting measurement. The measurement can be started by disconnecting the 4G modem. The green led goes off and after a while, the red should start blinking if the VectorNav does not have fix, or if everything seem to be fine, the red led is turned on. It is still recommend to wait for GPS to acquire better stability, but the recording is running.

When measurement are done, the recording can be stopped by reconnecting the 4G modem. The red led shuts off and the green led starts to blink as files are upload to github/gitlab. When the upload is done, the green led stabilize.

The logger can be turn off by turning the power/shutdown switch off, and waiting for 10-30 seconds for all lights to go off. When logger is off, the USB power cable can be disconnected with care, and battery removed.

Note: JYU version has reverse switch direction compared to other loggers, on is out, off is towards the antenna.

## 0.5 SSH access

The datalogger have SSH server running, and they can be accessed by connecting the datalogger via ethernet. The network should have DHCP to give IP address for the datalogger. For example internet sharing on Mac and Linux can be used for connecting the datalogger straight to the computer.

The IP of the datalogger can possibly found using nmap: nmap -sn 192.168.2.1-255 where IP range is subnet defined for network. The SSH connection can be mad with command ssh pi@192.168.2.3 where IP is the IP of the datalogger, and pi is the username.

Username for Raspberry Pi based datalogger is pi. Password is raspberry for pi and openkin for openkin.

12

13

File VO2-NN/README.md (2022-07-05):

## NORE: SUBJECT 2 HERE MEANS SUBJECT 3

### EvaluateTable

| ModelName 								 | Pred1					 	|Pred2	 			 | 
|---|---|
|Best_nha_bao_model_bidir.h5			 | |0.3535 |
|ModelTrained-12									 |0. 			| |
|ModelTrained-121 | |0.2020 |

Some important link

[Normalize columns of pandas data frame](https://stackoverflow.com/questions/26414913/normalize-columns-of-pandas-data-frame)

[Solving TensorFlow cuDNN Initialization Failure Problem](https://leimao.github.io/blog/TensorFlow-cuDNN-Failure/)

It has been a few times that I ran into the following error when I was using TensorFlow in the Docker container.

```
Unknown: Failed to get convolution algorithm. This is probably because cuDNN failed to initialize, so try looking to see if a warning log message was printed above.
```
It seems that it is because cuDNN failed to initialize. However, the reasons behind causing this are unknown.

Usually restarting the computer would solve the problem. However, if we don’t want to spend time restarting the computer, there are some quick solutions.

## TensorFlow-Keras 1.x

```
config = tf.ConfigProto()
config.gpu_options.allow_growth = True
tf.keras.backend.set_session(tf.Session(config=config))
```

## TensorFlow 2.x

```
gpu_devices = tf.config.experimental.list_physical_devices('GPU')
for device in gpu_devices:
    tf.config.experimental.set_memory_growth(device, True)
```

## TensorFlow Allow Growth

By default, TensorFlow would use all the GPU memory regardless of the size of the model you are running. 

That is also why we would need to specify the visible GPU devices when we are running the model on a multi-GPU server to prevent collisions with others. To only use the memory required for the model, we set the GPU memory to allow growth.

But it still remains mysterious to me why cuDNN sometimes would fail to initialize if the GPU memory does not allow growth.

## References

[TensorFlow 1.x Bug](https://github.com/tensorflow/tensorflow/issues/24828)

[keras LSTM Fail to find the dnn implementation #36508](https://github.com/tensorflow/tensorflow/issues/36508)

[TensorFlow 2.x - Limiting GPU Memory Growth](https://www.tensorflow.org/guide/gpu#limiting_gpu_memory_growth)

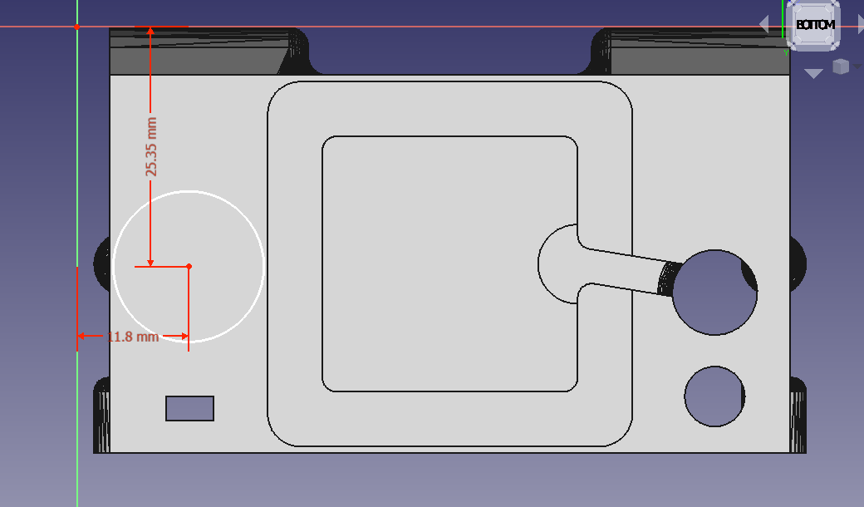
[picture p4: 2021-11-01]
3d/MyFirstDataLoggerCase/blockbase_design_number_4.png

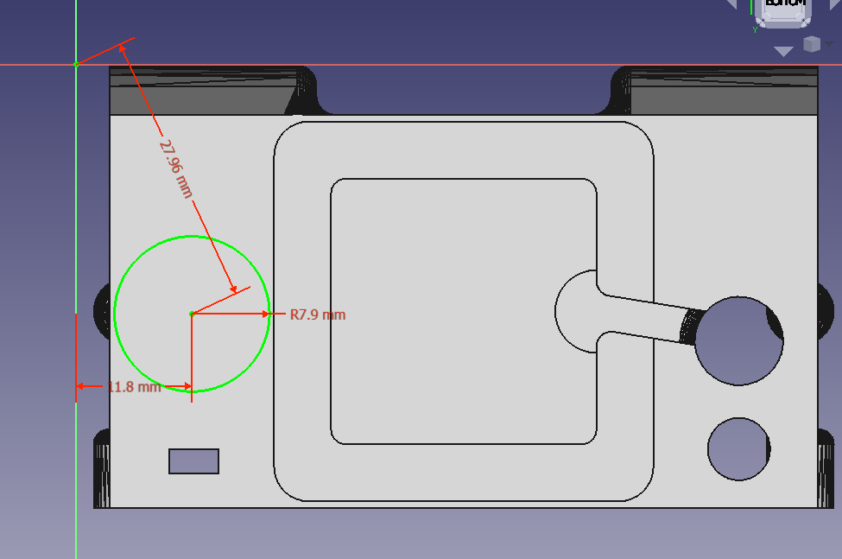
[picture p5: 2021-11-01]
3d/MyFirstDataLoggerCase/blockbase_design_number_3.png

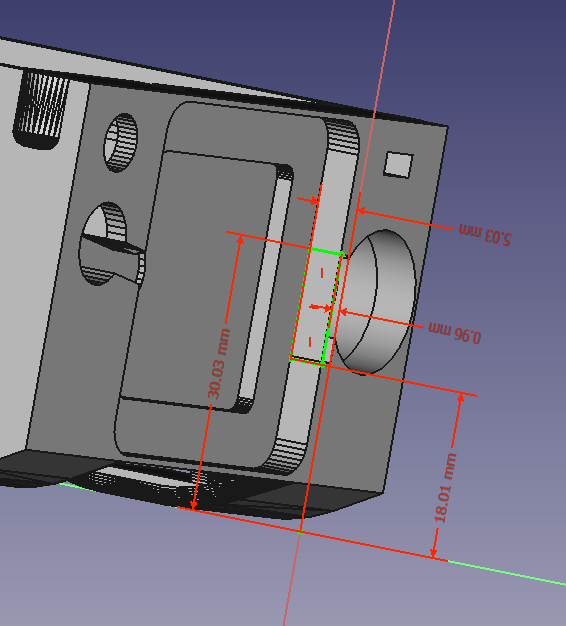
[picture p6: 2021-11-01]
3d/MyFirstDataLoggerCase/blockbase_design_number_1.png

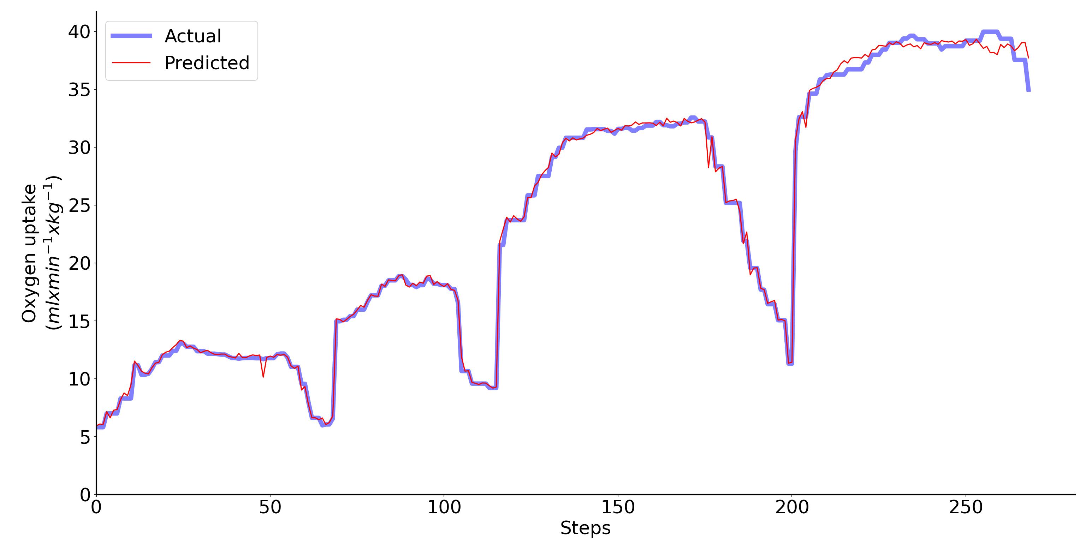
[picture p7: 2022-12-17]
paperSource/withHR_Subj9.jpg

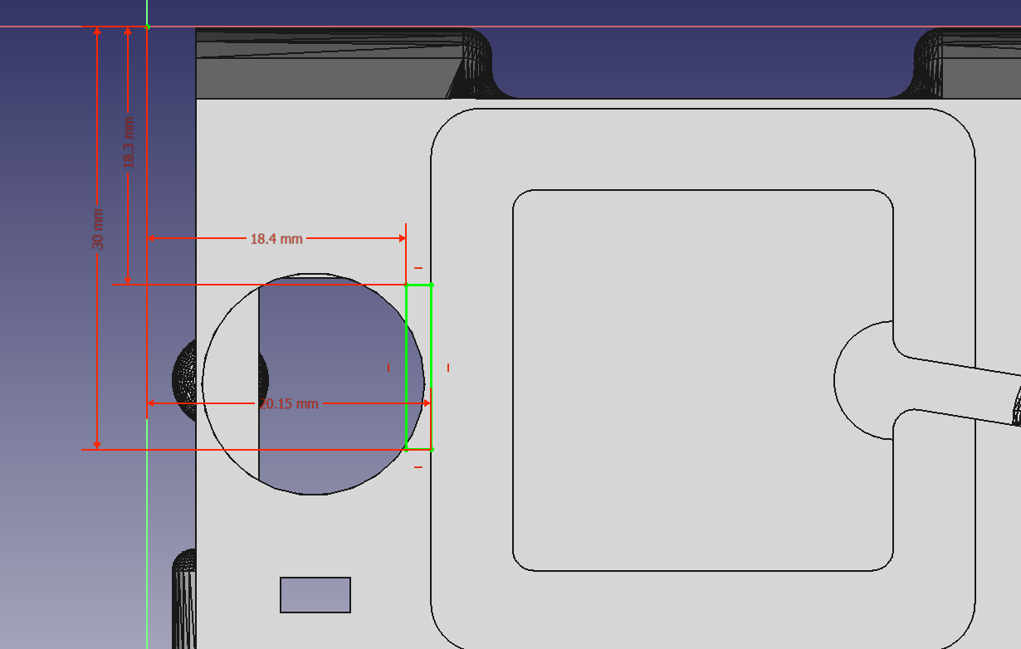
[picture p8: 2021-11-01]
3d/MyFirstDataLoggerCase/blockbase_design_number_2.png

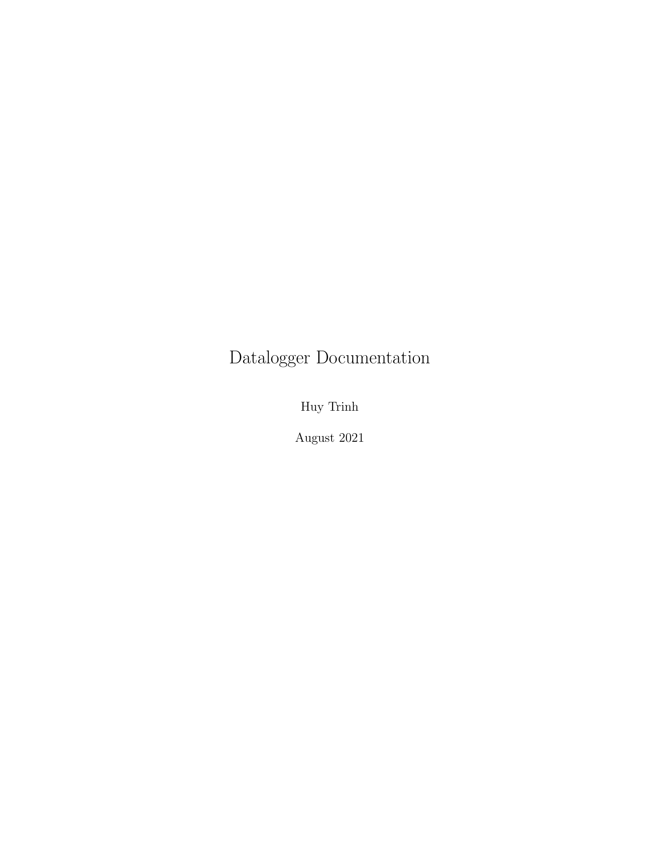
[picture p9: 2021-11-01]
doc/DataLogger-01.png

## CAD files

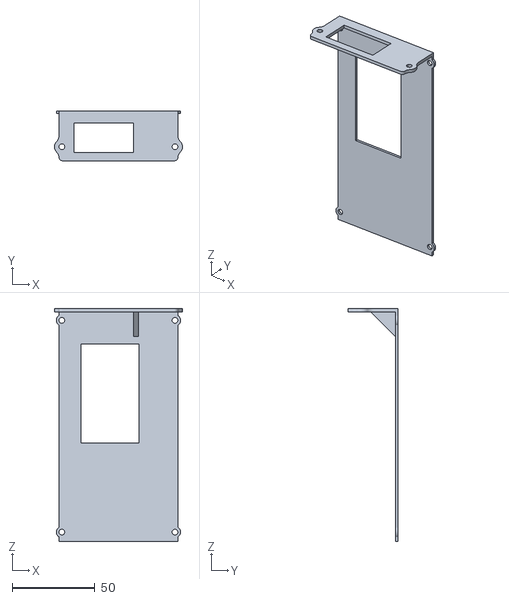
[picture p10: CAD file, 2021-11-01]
3d/MyFirstDataLoggerCase/rpi_case_assembly_v1_84 - rpi_lid2_v1_83-1_withhole.stl
77.6 x 30.0 x 141.1

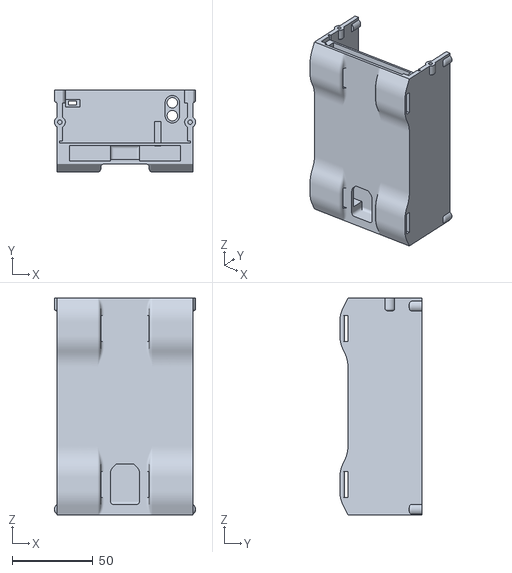
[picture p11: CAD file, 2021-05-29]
3d/STL/minnowboard_case_assembly_v_3_5 - minnow_blockbase_v3_5-1.STL
87.6 x 51.0 x 134.5

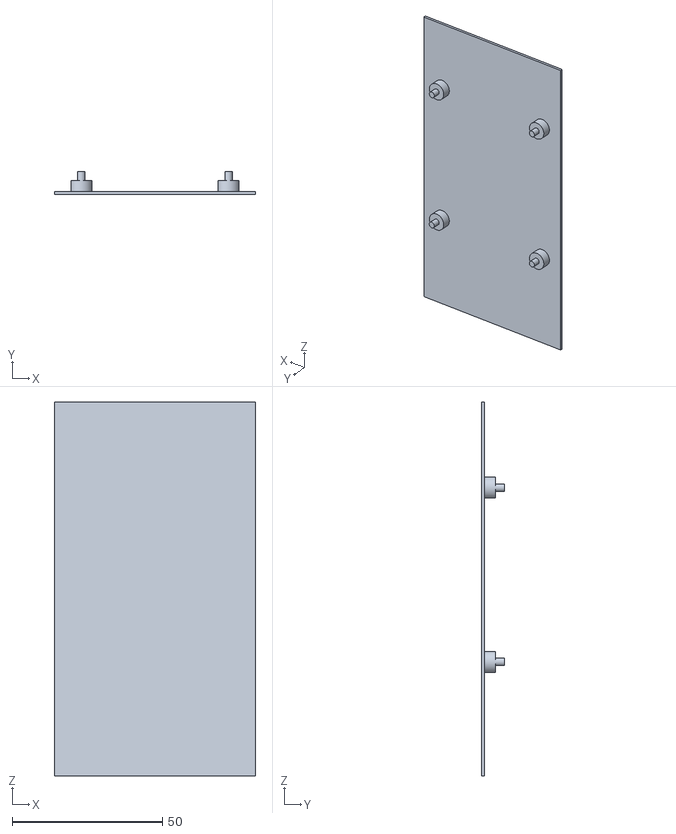
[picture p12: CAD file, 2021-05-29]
3d/STL/rpi_case_assembly_v1_7-vectornav - rpi_base_v1_7-fine.STL
67.0 x 7.50 x 124.5

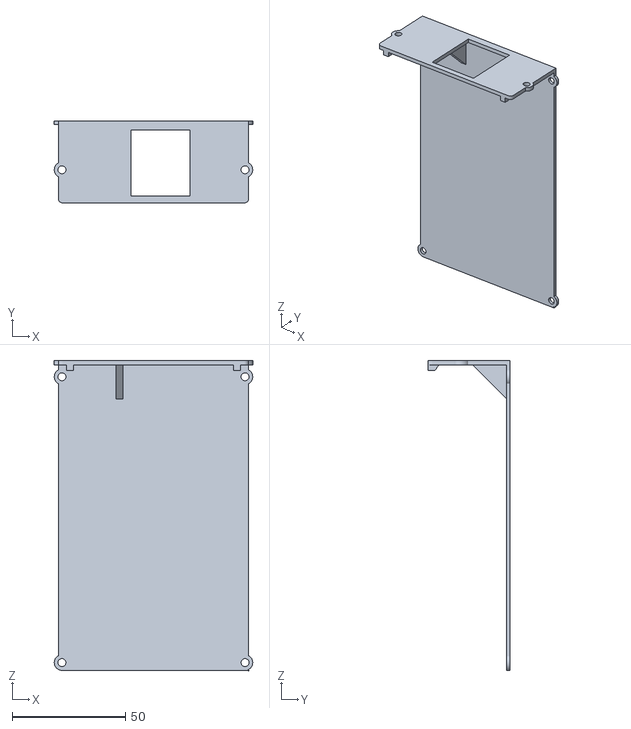
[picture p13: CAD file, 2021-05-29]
3d/STL/minnowboard_case_assembly_v_3_5 - minnow_lid_v3_5-1.STL
87.5 x 36.1 x 136.7

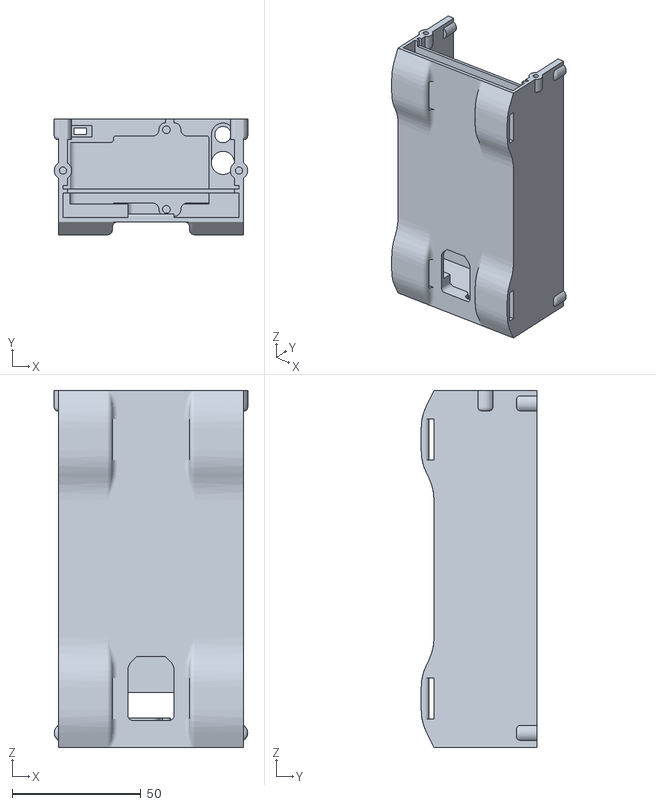
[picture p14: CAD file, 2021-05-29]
3d/STL/rpi_case_assembly_v1_84 - rpi_blockbase_v1_83-1.STL
75.3 x 45.0 x 138.9

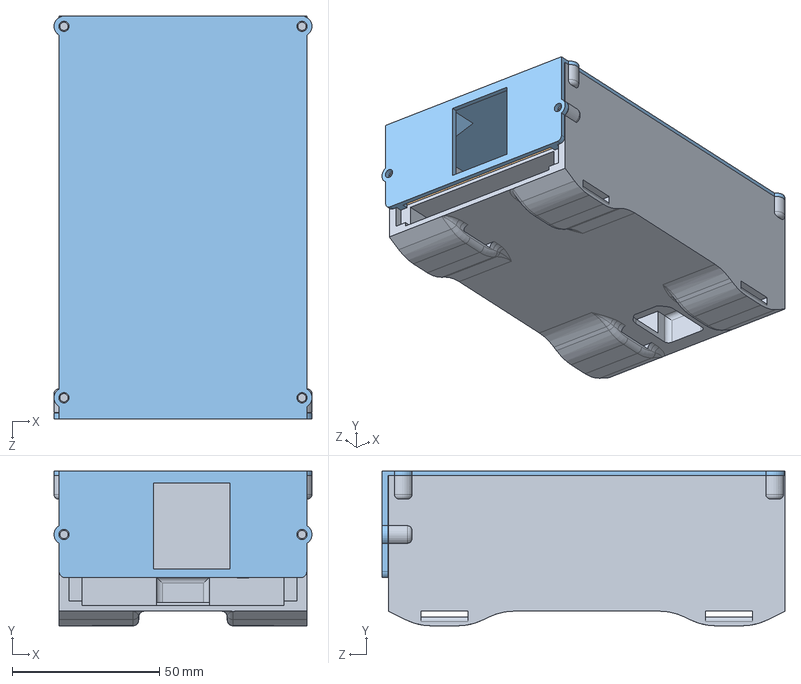
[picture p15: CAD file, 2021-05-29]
3d/Solidworks/minnowboard_case_assembly_v_3_5.SLDASM
87.5 x 52.5 x 136.7 mm
minnow_blockbase_v3_5
minnow_base_v3_5
minnow_lid_v3_5

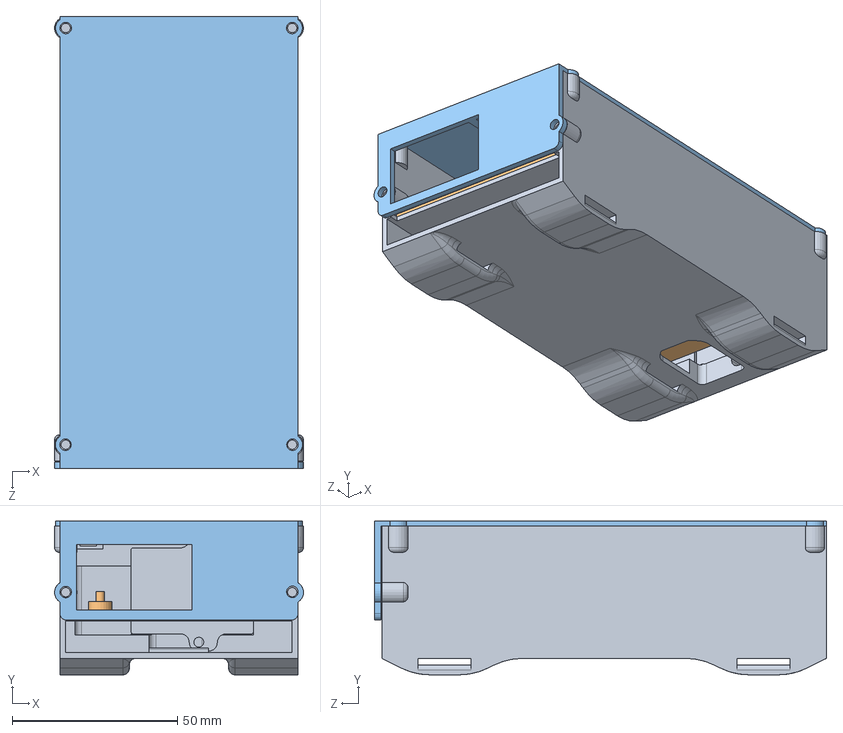
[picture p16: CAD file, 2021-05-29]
3d/Solidworks/rpi_case_assembly-vn200_v1_7.SLDASM
75.3 x 46.5 x 136.7 mm
rpi_blockbase_v1_7
rpi_base_v1_7
rpi_lid2_v1_7

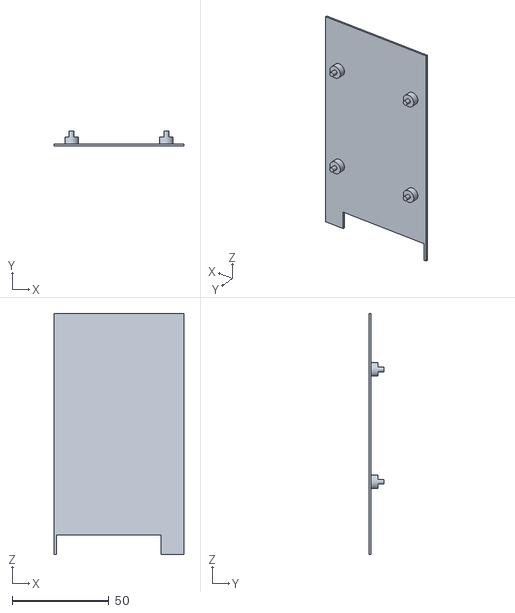
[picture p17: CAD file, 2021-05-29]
3d/STL/rpi_case_assembly_v1_84 - rpi_base_v1_83-1.STL
67.0 x 7.50 x 124.5

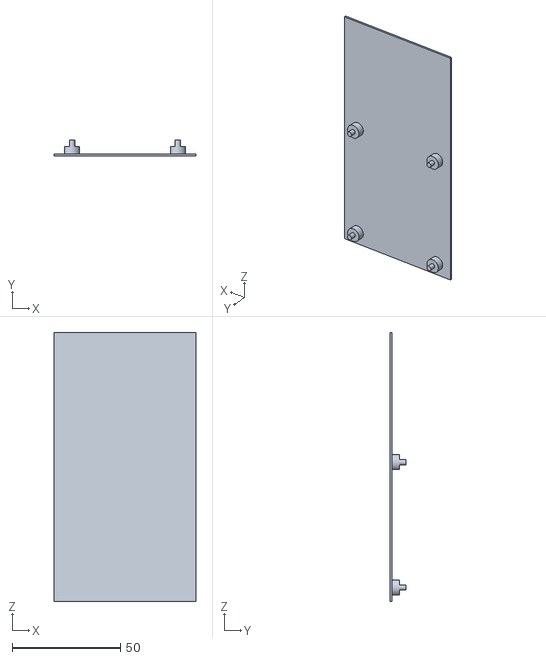
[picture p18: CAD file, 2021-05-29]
3d/STL/rpi_case_assembly_v1_4 - rpi_base_v1_4-1.STL
65.5 x 7.50 x 124.5

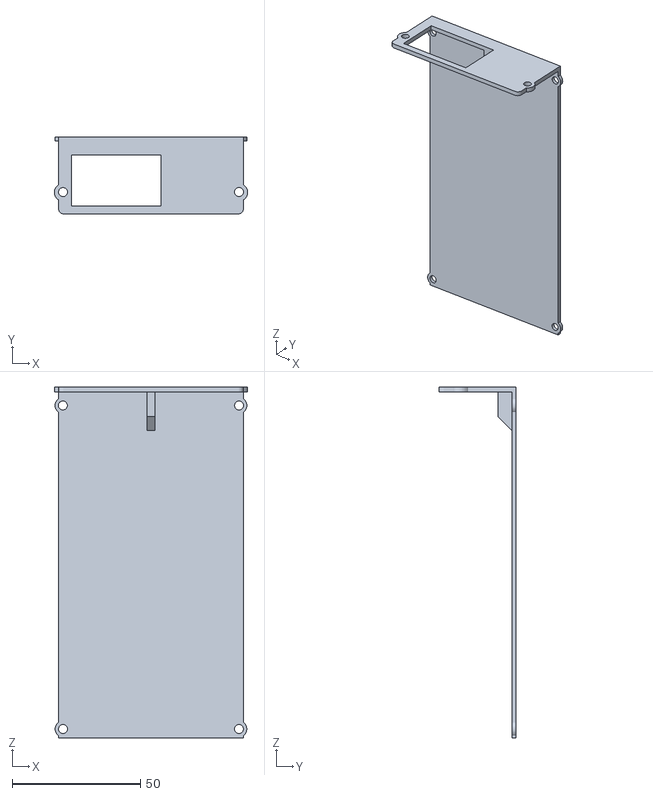
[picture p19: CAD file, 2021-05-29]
3d/STL/rpi_case_assembly_v1_7-vectornav - rpi_lid2_v1_7-1-1.STL
75.3 x 29.9 x 136.7

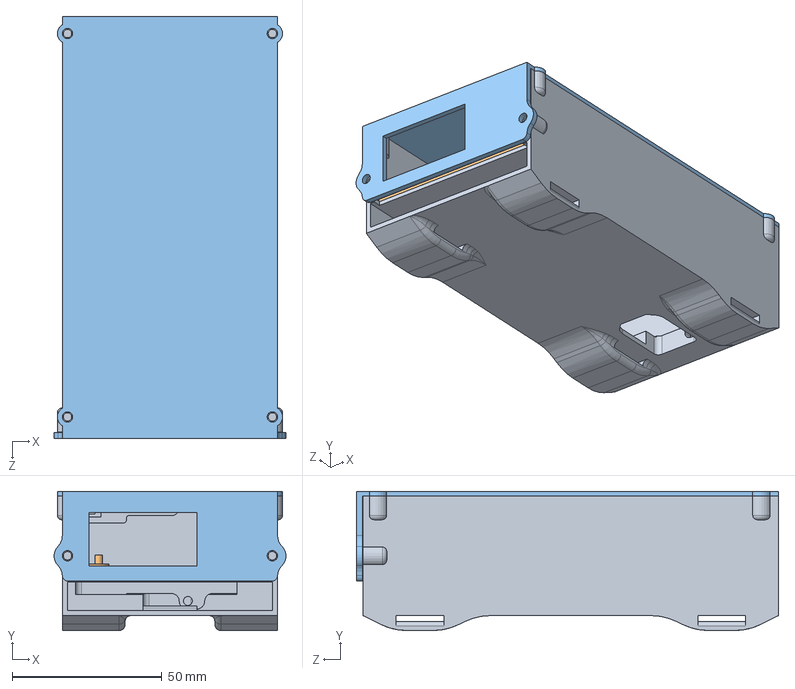
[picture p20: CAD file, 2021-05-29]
3d/Solidworks/rpi_case_assembly_v1_84.SLDASM
77.6 x 46.5 x 141.1 mm
rpi_blockbase_v1_84
rpi_base_v1_84
rpi_lid2_v1_84

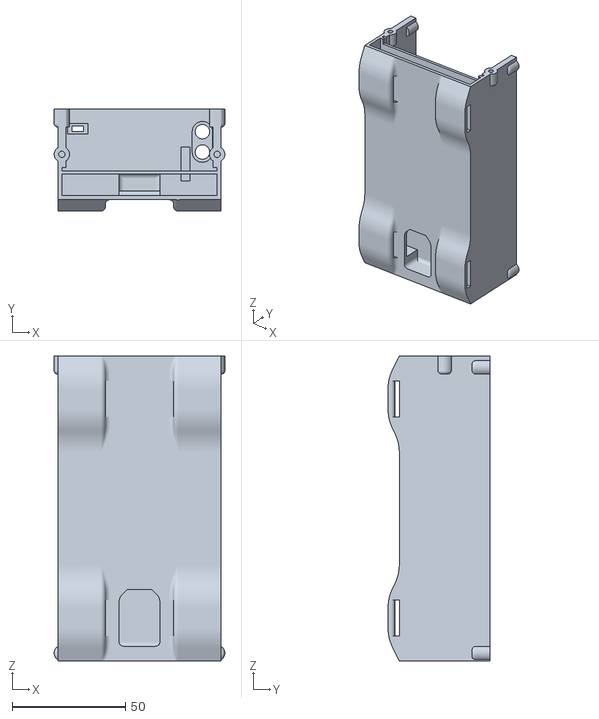
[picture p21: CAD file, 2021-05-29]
3d/STL/rpi_case_assembly_v1_4 - rpi_blockbase_v1_4-1.STL
75.3 x 45.0 x 134.5

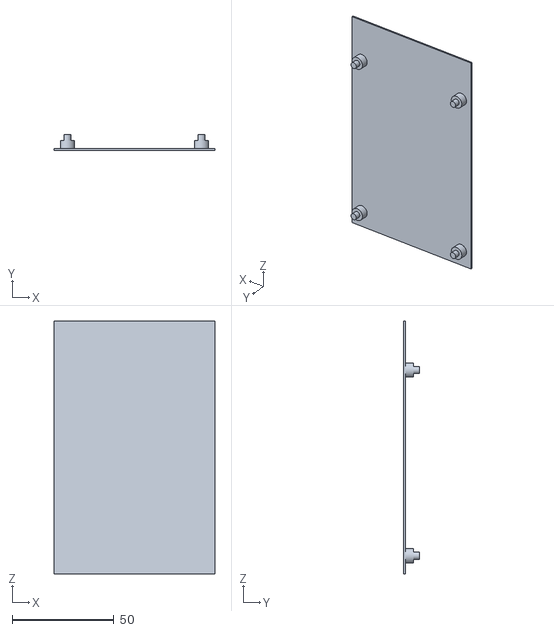
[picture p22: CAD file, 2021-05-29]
3d/STL/minnowboard_case_assembly_v_3_5 - minnow_base_v3_5-1.STL
79.0 x 7.85 x 124.5

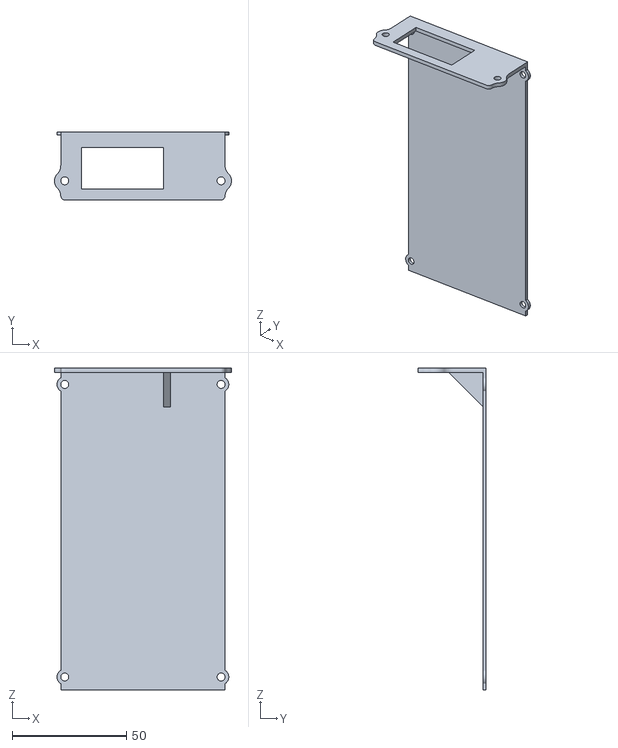
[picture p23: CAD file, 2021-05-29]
3d/STL/rpi_case_assembly_v1_84 - rpi_lid2_v1_83-1.STL
77.6 x 30.0 x 141.1

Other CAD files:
3d/STL/rpi_case_assembly_v1_7-vectornav - rpi_base_v1_7-1-1.STL
3d/STL/rpi_case_assembly_v1_7-vectornav - rpi_lid2_v1_7-fine.STL
3d/STL/rpi_case_assembly_v1_4 - rpi_lid2_v1_4-1.STL
3d/STL/rpi_case_assembly_v1_7-vectornav - rpi_blockbase_v1_7-1-1.STL
3d/FreeCAD/pozyx_adapter_v4.fcstd
3d/FreeCAD/pozyx_rpi_adapter_v0.4.fcstd
3d/MyFirstDataLoggerCase/blockbase_allholes_test2.stl
3d/STL/gps-hole-cover.STL
3d/STL/pozyx_adapter_v4.stl
3d/STL/pozyx_rpi_adapter_v0.4.stl
3d/STL/rpi_blockbase_v1_5-vn200.STL
3d/STL/rpi_blockbase_v1_6-vn200.STL
3d/Solidworks/gps-hole-cover.SLDPRT
3d/Solidworks/minnow_base_v3_5.SLDPRT
3d/Solidworks/minnow_blockbase_v3_5.SLDPRT
3d/Solidworks/minnow_lid_v3_5.sldprt
3d/Solidworks/rpi_base_v1_4.SLDPRT
3d/Solidworks/rpi_base_v1_7.SLDPRT
3d/Solidworks/rpi_base_v1_84.SLDPRT
3d/Solidworks/rpi_blockbase-vn200_v1_7.SLDPRT
3d/Solidworks/rpi_blockbase_v1_4.SLDPRT
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

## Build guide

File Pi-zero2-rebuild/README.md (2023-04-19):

### Rebuild Raspberry Pi zero 2

Current error when run `pi@raspberrypi:~/ros_catkin_ws $ catkin_make -DCATKIN_WHITELIST_PACKAGES="vectornav"`



```
pi@raspberrypi:~/ros_catkin_ws/src $ ls geometry2/
tf2  tf2_kdl  tf2_msgs  tf2_py  tf2_ros
```

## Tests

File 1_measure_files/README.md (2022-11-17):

## Useful link

[Diagnose udner/over fit in LSTM](https://machinelearningmastery.com/diagnose-overfitting-underfitting-lstm-models/)

[Understand impact of learning rate](https://machinelearningmastery.com/understand-the-dynamics-of-learning-rate-on-deep-learning-neural-networks/)

## This repo contains all neccessary files for measurement day

Validate normal `inputFeatures9_sorted.mat` train 850 epochs, validation_split=0.33





## With `inputFeatures9_sorted_99.mat`


### Decrease learning rate to 0.01 and 500 epochs



## Without shuffle

## With sorted



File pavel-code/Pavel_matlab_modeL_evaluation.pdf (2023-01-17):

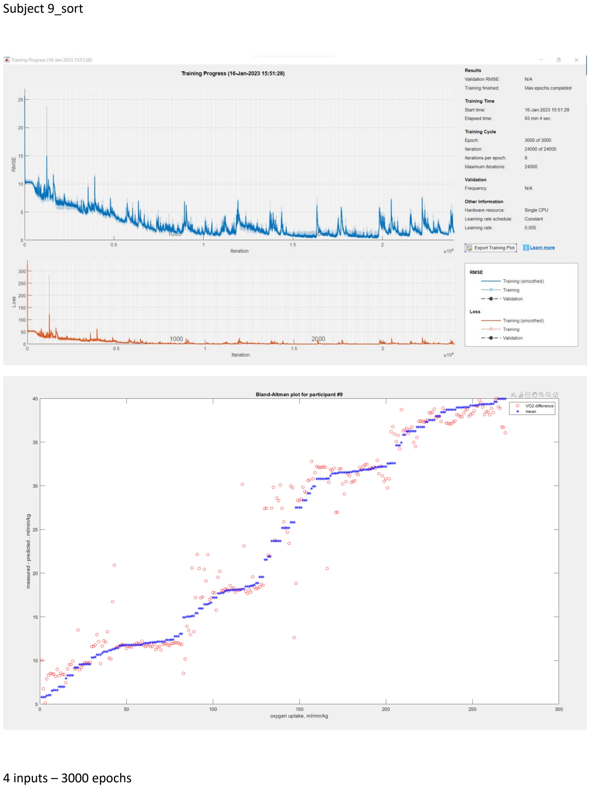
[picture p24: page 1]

Subject 9_sort

4 inputs – 3000 epochs

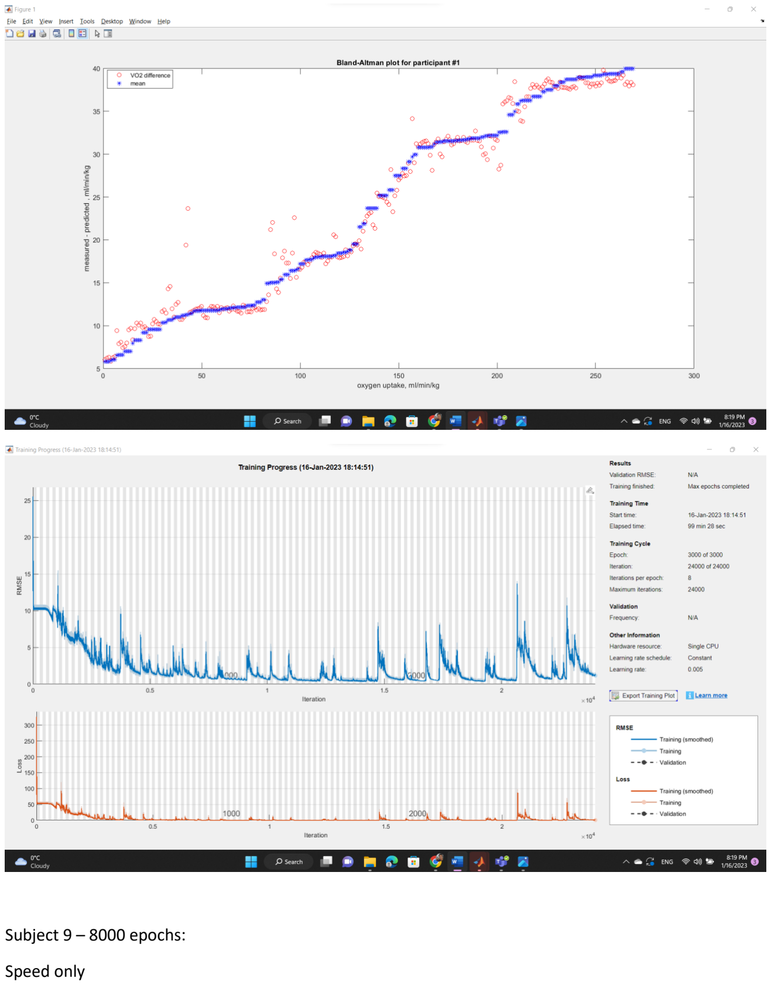
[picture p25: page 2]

Subject 9 – 8000 epochs:

Speed only

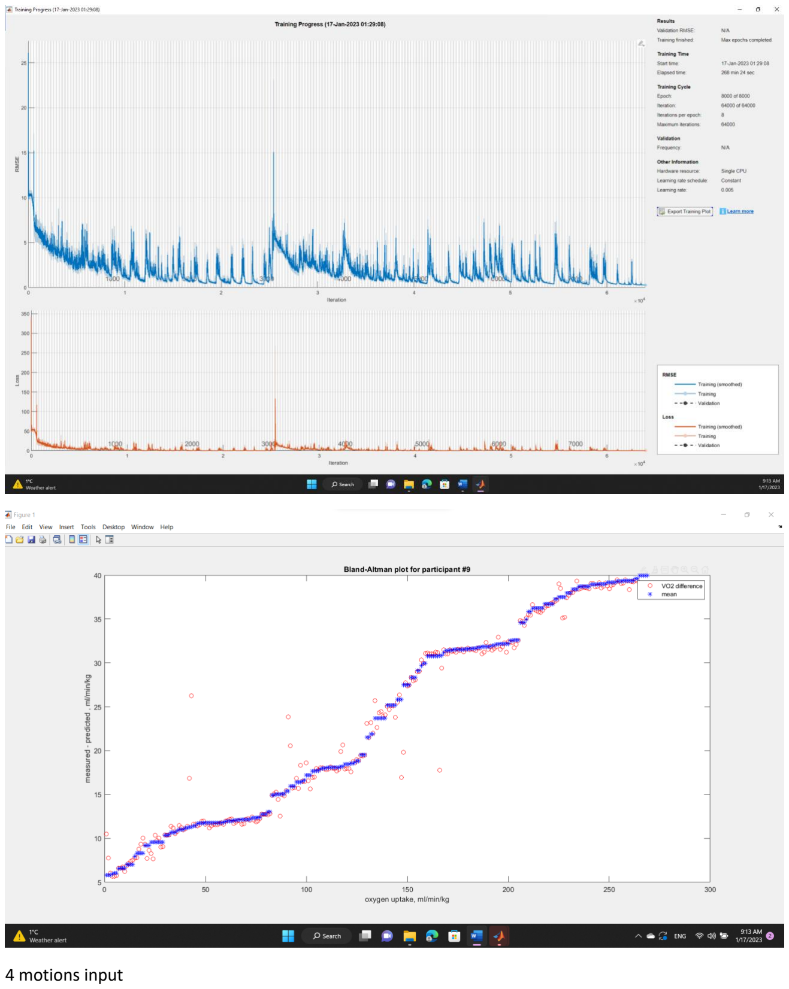
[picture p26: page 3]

4 motions input

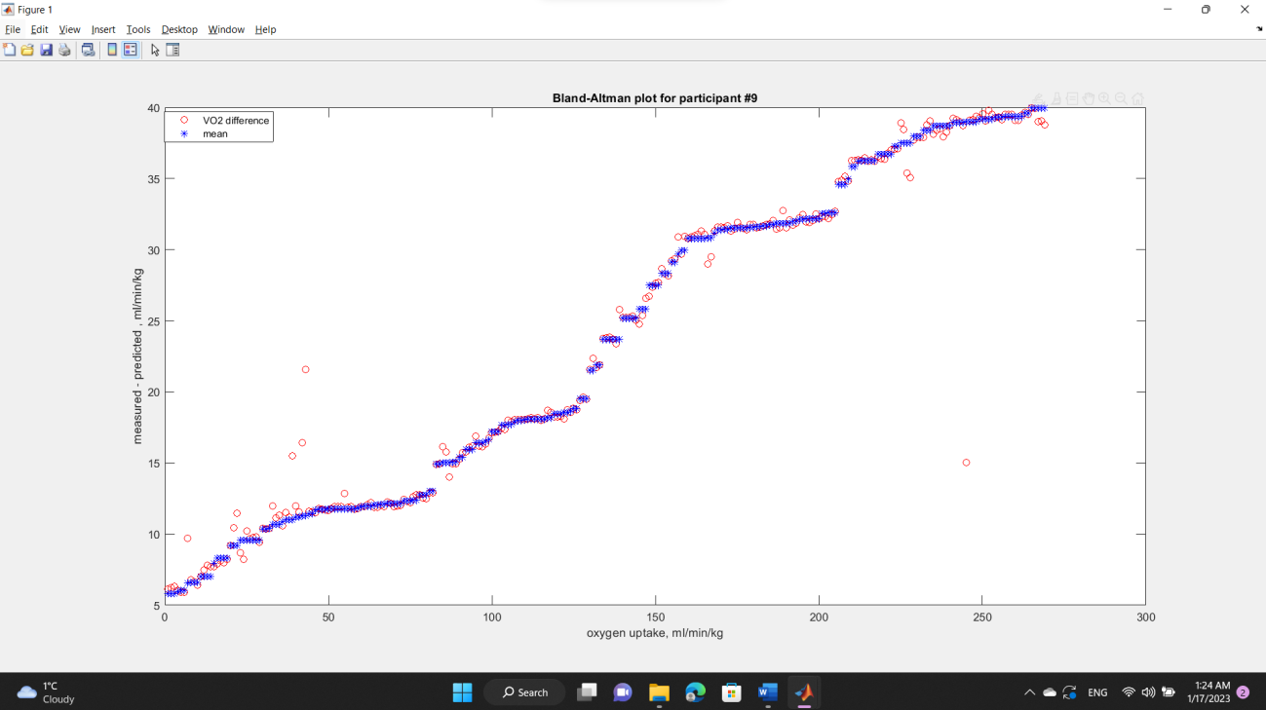
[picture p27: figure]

Subject 10 – 8000 epochs:

Speed only

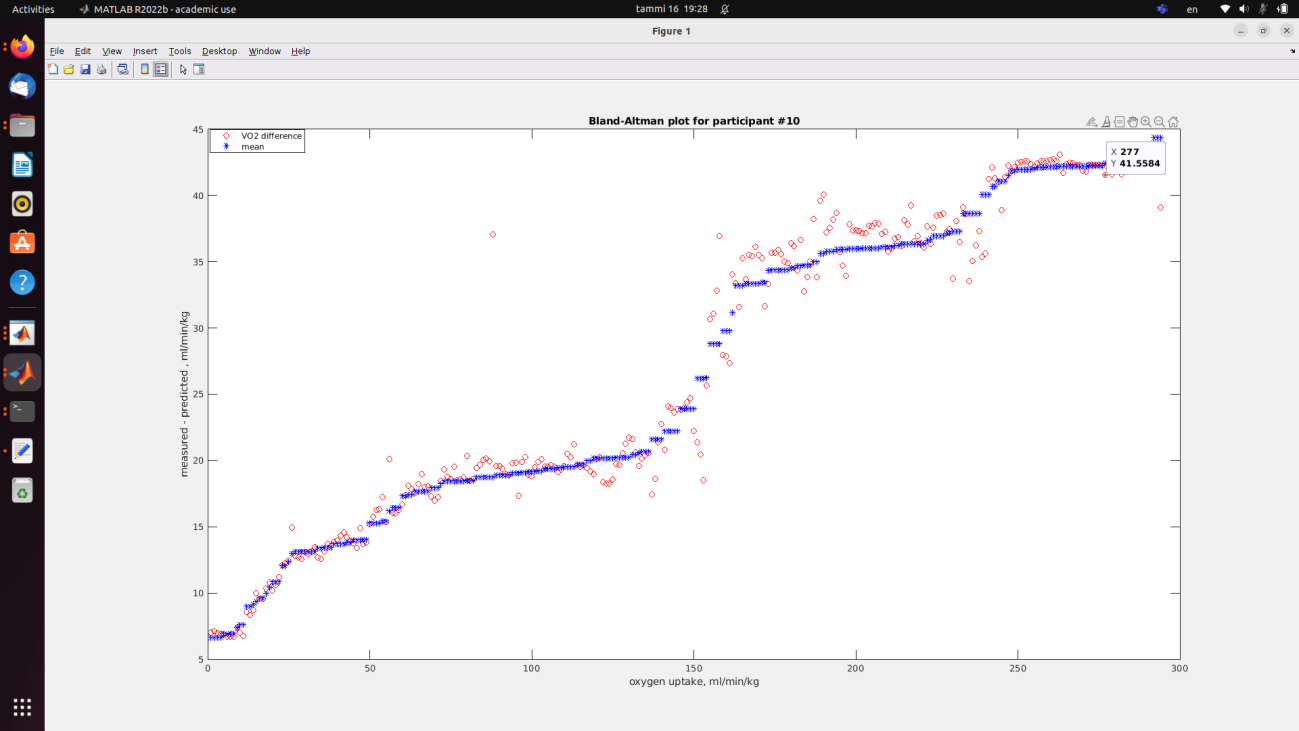
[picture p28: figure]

# 4 motion inputs

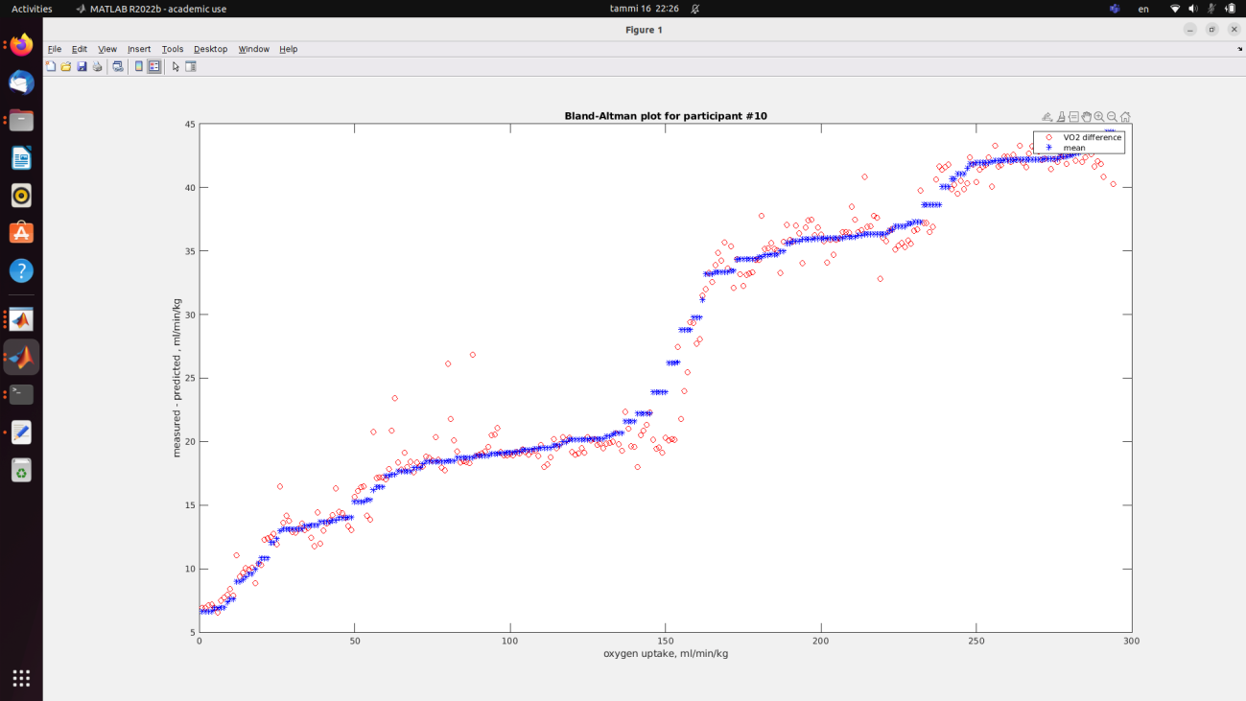
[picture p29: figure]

Subject 11 – 8000 epochs:

# 4 motion inputs

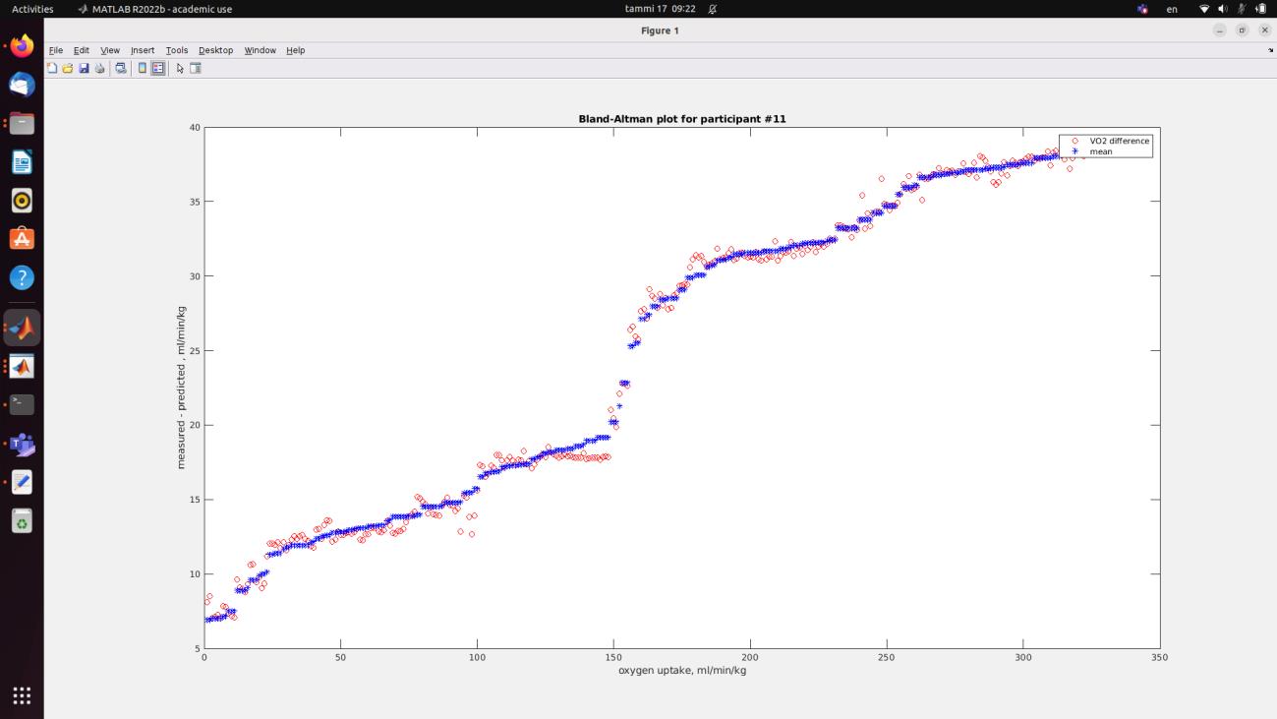
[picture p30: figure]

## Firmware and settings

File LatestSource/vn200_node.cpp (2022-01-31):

/* * MIT License (MIT)
 *
 * Copyright (c) 2013 Dereck Wonnacott <dereck@gmail.com>
 *
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
 */


#include <stdio.h>
#include <unistd.h>
#include <math.h>
#include <stdlib.h>     /* exit, EXIT_FAILURE */

#include <vn/sensors.h>

#include <ros/ros.h>
#include <tf/tf.h>
#include <signal.h>
#include <time.h>
// Message Types
#include <vectornav/utc_time.h>
#include <vectornav/imugps.h>

#include <ros/xmlrpc_manager.h>

#include <iostream>
#include <fstream>

using namespace vn::protocol::uart;
using namespace vn::sensors;

// Signal-safe flag for whether shutdown is requested
sig_atomic_t volatile g_request_shutdown = 0;

const char ledpipe[] = "/tmp/ledpipe0";
const char insrecording[] = "/tmp/insrecording";
const char on[] = "ON\n";
bool fix = false;
unsigned int ledcount = 0;

// Params
std::string imu_frame_id, gps_frame_id;

// Publishers
ros::Publisher pub_ins;

// Device
vn::sensors::VnSensor vn200;

int ins_seq           = 0;
int msg_cnt           = 0;
int last_group_number = 0;


std::string port;
char vn_error_msg[100];

struct utc_time_struct
{
    uint8_t year;
    uint8_t month;
    uint8_t day;
    uint8_t hour;
    uint8_t minute;
    uint8_t second;
    uint16_t millisecond;
};

struct ins_binary_data_struct
{
    uint64_t gps_time;
    vn::math::vec4f orientation;
    vn::math::vec3f angular_rate;
    vn::math::vec3d lla;
    vn::math::vec3f vel_ned;
    vn::math::vec3f accel;
    vn::math::vec4f dtheta;
    vn::math::vec3f dvel;
    uint8_t         fix;
    vn::math::vec3d gpslla;
    vn::math::vec3f gpsvel_ned;
};

ins_binary_data_struct ins_binary_data;

int ins_msg_count = 0;

const unsigned raw_imu_max_rate = 800;

const unsigned ins_group_signature = BINARYGROUP_COMMON | BINARYGROUP_GPS;


void publish_ins_data()
{
    ins_seq++;
    ros::Time timestamp =  ros::Time::now();

    if (pub_ins.getNumSubscribers() > 0)
    {
        vectornav::imugps msg_ins;
        msg_ins.header.stamp    = timestamp;
        msg_ins.header.frame_id = "ins";

        msg_ins.time    = ins_binary_data.gps_time;

        msg_ins.orientation.x = ins_binary_data.orientation[0];
        msg_ins.orientation.y = ins_binary_data.orientation[1];
        msg_ins.orientation.z = ins_binary_data.orientation[2];
        msg_ins.orientation.w = ins_binary_data.orientation[3];

        msg_ins.angular_velocity.x = ins_binary_data.angular_rate[0];
        msg_ins.angular_velocity.y = ins_binary_data.angular_rate[1];
        msg_ins.angular_velocity.z = ins_binary_data.angular_rate[2];

        msg_ins.LLA.x = ins_binary_data.lla[0];
        msg_ins.LLA.y = ins_binary_data.lla[1];
        msg_ins.LLA.z = ins_binary_data.lla[2];

        msg_ins.nedvel.x = ins_binary_data.vel_ned[0];
        msg_ins.nedvel.y = ins_binary_data.vel_ned[1];
        msg_ins.nedvel.z = ins_binary_data.vel_ned[2];

        msg_ins.linear_acceleration.x = ins_binary_data.accel[0];
        msg_ins.linear_acceleration.y = ins_binary_data.accel[1];
        msg_ins.linear_acceleration.z = ins_binary_data.accel[2];

        msg_ins.dtime = ins_binary_data.dtheta[0];

        msg_ins.dtheta[0] = ins_binary_data.dtheta[1];
        msg_ins.dtheta[1] = ins_binary_data.dtheta[2];
        msg_ins.dtheta[2] = ins_binary_data.dtheta[3];

        msg_ins.dvel[0] = ins_binary_data.dvel[0];
        msg_ins.dvel[1] = ins_binary_data.dvel[1];
        msg_ins.dvel[2] = ins_binary_data.dvel[2];

        msg_ins.fix = ins_binary_data.fix;
	if (ins_binary_data.fix > 2) {
            std::fstream fs;
            ledcount++;
            std::ifstream rec;
            try {
                rec.open(insrecording, std::ios::in);
                std::string line;
                getline(rec, line);
                if (line == "ON" && (!fix || ledcount > 3000)) {
                    ledcount = 0;
                    try {
                        fs.open(ledpipe, std::fstream::out|std::fstream::app);
                        fs << on;
                        fix = true;
                    } catch (...) {
                        //
                    }
                }
            } catch (...) {}
        }

        msg_ins.gpsLLA.x = ins_binary_data.gpslla[0];
        msg_ins.gpsLLA.y = ins_binary_data.gpslla[1];
        msg_ins.gpsLLA.z = ins_binary_data.gpslla[2];

        msg_ins.gpsnedvel.x = ins_binary_data.gpsvel_ned[0];
        msg_ins.gpsnedvel.y = ins_binary_data.gpsvel_ned[1];
        msg_ins.gpsnedvel.z = ins_binary_data.gpsvel_ned[2];

        pub_ins.publish(msg_ins);
    }
}

void binaryMessageReceived(void * user_data, Packet & p, size_t index)
{
    std::string raw_data;
    if (p.type() == Packet::TYPE_BINARY && p.isValid()) {
        switch (p.groups()) {
        case ins_group_signature:
            ++ins_msg_count;
            ins_binary_data.gps_time =      p.extractUint64();
            ins_binary_data.orientation =   p.extractVec4f();
            ins_binary_data.angular_rate =  p.extractVec3f();
            ins_binary_data.lla =           p.extractVec3d();
            ins_binary_data.vel_ned =       p.extractVec3f();
            ins_binary_data.accel =         p.extractVec3f();
            ins_binary_data.dtheta =        p.extractVec4f();
            ins_binary_data.dvel =          p.extractVec3f();
            ins_binary_data.fix =           p.extractUint8();
            ins_binary_data.gpslla =        p.extractVec3d();
            ins_binary_data.gpsvel_ned =    p.extractVec3f();

            publish_ins_data();

            /*if (remainder(ins_msg_count, 100) == 0) {
                ins_msg_count = 0;
                ROS_INFO_STREAM("INS_Time: " << ins_binary_data.gps_time*1E-9 << " Yaw: " <<
                        ins_binary_data.ypr[0] << " Pitch: " << ins_binary_data.ypr[1] <<
                        " Roll: " << ins_binary_data.ypr[2] << " INS_Status: " <<
                        ins_binary_data.ins_status << " latitude: " << ins_binary_data.lla[0] <<
                        " longitude: " << ins_binary_data.lla[1] << " altitude: " << ins_binary_data.lla[2]);
            }
            */
            break;
        default:
            ROS_WARN("Received unknown group signature from vectornav");
        }
    } else {
        ROS_WARN("Received invalid packet from vectornav.");
	ROS_INFO("%s", p.datastr().c_str());
        // Ignore non-binary packets for now.
    }
}

bool dividesEvenly(unsigned numerator, unsigned denominator)
{
    unsigned dividend = numerator / denominator;
    return numerator == denominator * dividend;
}

void mySigintHandler(int sig)
{
    g_request_shutdown = 1;
}

// Replacement "shutdown" XMLRPC callback
void shutdownCallback(XmlRpc::XmlRpcValue& params, XmlRpc::XmlRpcValue& result)
{
    int num_params = 0;

    if (params.getType() == XmlRpc::XmlRpcValue::TypeArray) {
        num_params = params.size();
    }
    if (num_params > 1) {
        std::string reason = params[1];
        ROS_WARN("Shutdown request received. Reason: [%s]", reason.c_str());
        g_request_shutdown = 1; // Set flag
    }

    result = ros::xmlrpc::responseInt(1, "", 0);
}

/////////////////////////////////////////////////
int main(int argc, char* argv[])
{
    // Initialize ROS;
    ros::init(argc, argv, "vectornav", ros::init_options::NoSigintHandler);
    ros::NodeHandle n;
    ros::NodeHandle n_("~");

    // Read Parameters
    int baud, poll_rate_ins, poll_rate_gps, poll_rate_imu, async_output_type, async_output_rate,
        binary_data_output_port, binary_gps_data_rate, binary_ins_data_rate,
        binary_imu_data_rate, target_baud;

    int retry_cnt = 0;

    // Override XMLRPC shutdown
    ros::XMLRPCManager::instance()->unbind("shutdown");
    ros::XMLRPCManager::instance()->bind("shutdown", shutdownCallback);
    signal(SIGINT, mySigintHandler);

    n_.param<std::string>("serial_port" , port     , "/dev/ttyUSB0");
    n_.param<int>(        "serial_baud" , baud     , 115200);
    n_.param<int>(        "poll_rate_gps"   , poll_rate_gps, 5);
    n_.param<int>(        "poll_rate_ins"   , poll_rate_ins, 20);
    n_.param<int>(        "poll_rate_imu"   , poll_rate_imu, 100);

    n_.param<std::string>("imu/frame_id", imu_frame_id, "LLA");
    n_.param<std::string>("gps/frame_id", gps_frame_id, "LLA");

    // Type: 0 None, 19 IMU, 20 GPS, 22 INS
    n_.param<int>(        "async_output_type"  , async_output_type, 0);
    n_.param<int>(        "async_output_rate"  , async_output_rate, 50);

    n_.param<int>(        "binary_data_output_port"  , binary_data_output_port, 1);
    n_.param<int>(        "binary_gps_data_output_rate"  , binary_gps_data_rate, 4);
    n_.param<int>(        "binary_ins_data_output_rate"  , binary_ins_data_rate, 20);
    n_.param<int>(        "binary_imu_data_output_rate"  , binary_imu_data_rate, 100);
    n_.param<int>(        "target_baud"  , target_baud, 921600);

    // Validate the rate inputs.
    if (binary_gps_data_rate < 1 || binary_gps_data_rate > raw_imu_max_rate) {
        ROS_FATAL_STREAM("binary_gps_data_output_rate of "
          << binary_gps_data_rate << " is out of range (1 - "
          << raw_imu_max_rate << ")");
        exit(EXIT_FAILURE);
    } else if (!dividesEvenly(raw_imu_max_rate, binary_gps_data_rate)) {
        ROS_FATAL_STREAM("binary_gps_data_rate does not evenly divide "
          << raw_imu_max_rate);
        exit(EXIT_FAILURE);
    }

    if (binary_ins_data_rate < 1 || binary_ins_data_rate > raw_imu_max_rate) {
        ROS_FATAL_STREAM("binary_ins_data_rate of "
          << binary_ins_data_rate << " is out of range (1 - "
          << raw_imu_max_rate << ")");
        exit(EXIT_FAILURE);
    } else if (!dividesEvenly(raw_imu_max_rate, binary_ins_data_rate)) {
        ROS_FATAL_STREAM("binary_ins_data_rate does not evenly divide "
          << raw_imu_max_rate);
        exit(EXIT_FAILURE);
    }

    if (binary_imu_data_rate < 1 || binary_imu_data_rate > raw_imu_max_rate) {
        ROS_FATAL_STREAM("binary_imu_data_rate of "
          << binary_imu_data_rate << " is out of range (1 - "
          << raw_imu_max_rate << ")");
        exit(EXIT_FAILURE);
    } else if (!dividesEvenly(raw_imu_max_rate, binary_imu_data_rate)) {
        ROS_FATAL_STREAM("binary_imu_data_rate does not evenly divide "
          << raw_imu_max_rate);
        exit(EXIT_FAILURE);
    }

    AsyncMode binary_data_output_mode =
      static_cast<AsyncMode>(binary_data_output_port);

    // Initialize Publishers
    //pub_ins     = n_.advertise<vectornav::ins>    ("ins", 1000);
    //pub_gps     = n_.advertise<vectornav::gps>    ("gps", 1000);
    //pub_sensors = n_.advertise<vectornav::sensors>("imu", 1000);
    pub_ins       = n_.advertise<vectornav::imugps> ("imugps", 100);

    // Initialize VectorNav
    //VN_ERROR_CODE vn_retval;
    ROS_INFO("Initializing vn200. Port:%s Baud:%d\n", port.c_str(), baud);

    std::vector<uint32_t> bauds = vn200.supportedBaudrates();
    bool connected = false;
    uint32_t connbaud = 0;

    for (std::vector<uint32_t>::reverse_iterator it = bauds.rbegin(); it != bauds.rend(); ++it) {
        try {
            ROS_INFO("Trying baud %d\n", *it);
            vn200.connect(port, *it);
        } catch (...) {
            continue;
        }
        if (vn200.isConnected()) {
            ROS_INFO("Connected?: %d", *it);
            //if (*it == target_baud) {
            //    connected = true;
            //    ROS_INFO("Target baud reached");
            //    break;
            //}
            try {
                vn200.writeSerialBaudRate(target_baud, binary_data_output_port, true);
                ROS_INFO("Connecting with target baud %d\n", target_baud);
                vn200.disconnect();
                vn200.connect(port, target_baud);
            } catch (...) {
                continue;
            }
            connbaud = *it;
            if (vn200.isConnected()) {
                ROS_INFO("Should be connected now");
                connected = true;
            }
            break;
        }
    }

    /*bool connected = false;

    try {
        vn200.connect(port, baud);
        connected = true;
    } catch (...) {
        connected = false;
    }

    if (baud != target_baud && connected) {
        ROS_INFO("Changing baud to %d", target_baud);
        try {
            vn200.writeSerialBaudRate(target_baud, binary_data_output_port, true);
            vn200.disconnect();
        } catch (...) {
            ROS_WARN("Couldn't change baud");
            throw;
        }
	//ros::shutdown();
	try {
            vn200.connect(port, target_baud);
            connected = true;
        } catch (...) {
            connected = false;
        }
    }*/

    if (!connected) {
        ROS_FATAL("Could not conenct to vn200 on port:%s @ Baud:%d;"
                "Did you add your user to the 'dialout' group in /etc/group?",
                port.c_str(),
                baud);
        exit(EXIT_FAILURE);
    }

    vn200.writeAsyncDataOutputFrequency(0);

    CommonGroup ins_common_group = COMMONGROUP_TIMEGPS | COMMONGROUP_QUATERNION
        | COMMONGROUP_ANGULARRATE | COMMONGROUP_POSITION
        | COMMONGROUP_VELOCITY | COMMONGROUP_ACCEL | COMMONGROUP_DELTATHETA;

    GpsGroup ins_gps_group = GPSGROUP_FIX | GPSGROUP_POSLLA | GPSGROUP_VELNED;

    BinaryOutputRegister ins_log_reg(
        binary_data_output_mode,
        raw_imu_max_rate / binary_ins_data_rate,
        ins_common_group,
        TIMEGROUP_NONE,
        IMUGROUP_NONE,
        ins_gps_group,
        ATTITUDEGROUP_NONE,
        INSGROUP_NONE);

    ROS_INFO("Writing binary output 1");
    vn200.writeBinaryOutput1(ins_log_reg);
    ROS_INFO("Written binary output 1");
    //vn200.writeBinaryOutput2(ins_log_reg);
    //vn200.writeBinaryOutput3(imu_log_reg);

//    ROS_INFO("About to set SynchronizationControl");

/*    vn::sensors::SynchronizationControlRegister sync_control(
        SYNCINMODE_COUNT,
        SYNCINEDGE_RISING,
        0, // sync in skip factor
        SYNCOUTMODE_GPSPPS,
        SYNCOUTPOLARITY_NEGATIVE,
        0, // sync out skip factor
        1000000); // a millisecond should be fine.

    vn200.writeSynchronizationControl(sync_control);
*/
    vn::math::vec3f position;

    // For JYU and new TTY
    position[0] = -0.004;
    position[1] = 0.0;
    position[2] = 0.008;

    vn200.writeGpsAntennaOffset(position);

    // Lower magnetometer velocity threshold for walking speeds
    InsAdvancedConfigurationRegister inssettings(
      true, ///< The useMag field.
      true, ///< The usePres field.
      true, ///< The posAtt field.
      true, ///< The velAtt field.
      true, ///< The velBias field.
      FOAMINIT_FOAMINITHEADINGPITCHROLLCOVARIANCE, ///< The useFoam field.
      0, ///< The gpsCovType field.
      5, ///< The velCount field.
      1.0, ///< The velInit field.
      1000.0, ///< The moveOrigin field.
      30.0, ///< The gpsTimeout field.
      1000.0, ///< The deltaLimitPos field.
      100.0, ///< The deltaLimitVel field.
      1.0, ///< The minPosUncertainty field.
      1.0 ///< The minVelUncertainty field.
    );
    vn200.writeInsAdvancedConfiguration(inssettings, false);

    ROS_INFO("Registering handler");
    vn200.registerAsyncPacketReceivedHandler(NULL, binaryMessageReceived);
    ROS_INFO("Registered");

    ros::Rate r(100);
    while (!g_request_shutdown) {
        ros::spinOnce();
        //usleep(500);
        r.sleep();
    }

    vn200.unregisterAsyncPacketReceivedHandler();
    ros::shutdown();
}

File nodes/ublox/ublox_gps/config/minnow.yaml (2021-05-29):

# Configuration Settings for RPi datalogger

debug: 1                    # Range 0-4 (0 means no debug statements will print)

device: /dev/ttyS4
frame_id: gps
rate: 5                     # in Hz
nav_rate: 1                 # [# of measurement cycles], recommended 1 Hz, may
                            # be either 5 Hz (Dual constellation) or
                            # 8 Hz (GPS only)
dynamic_model: pedestrian   # Airborne < 2G, 2D fix not supported (3D only),
                            # Max Alt: 50km
                            # Max Horizontal Velocity: 250 m/s,
                            # Max Vertical Velocity: 100 m/s
fix_mode: auto
enable_ppp: true            # Not supported by C94-M8P
dr_limit: 0

uart1:
  baudrate: 9600           # C94-M8P specific
#  in: 1                     # RTCM 3
#  out: 1                    # No UART out for rover

gnss:
  gps: true                  #
  glonass: true              # Supported by C94-M8P
#  reset_mode: 2             # Controlled Software reset
#  beidou: false             # Supported by C94-M8P
#  qzss: false               # Supported by C94-M8P
#  sbas: false               # Not supported by C94-M8P
#  galileo: true             #

inf:
    all: false

# Subscriptions
subscribe:
  all: false
  aid: false

  nav:
    sol: false
    pvt: true
    status: false
    velned: false
    svin: false
    posecef: false
    relposned: false
    svinfo: false

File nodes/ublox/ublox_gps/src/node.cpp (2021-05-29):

//==============================================================================
// Copyright (c) 2012, Johannes Meyer, TU Darmstadt
// All rights reserved.

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
// THIS SOFTWARE IS PROVIDED BY THE COPYRIGHT HOLDERS AND CONTRIBUTORS "AS IS"
// AND
// ANY EXPRESS OR IMPLIED WARRANTIES, INCLUDING, BUT NOT LIMITED TO, THE IMPLIED
// WARRANTIES OF MERCHANTABILITY AND FITNESS FOR A PARTICULAR PURPOSE ARE
// DISCLAIMED. IN NO EVENT SHALL THE COPYRIGHT HOLDER BE LIABLE FOR ANY
// DIRECT, INDIRECT, INCIDENTAL, SPECIAL, EXEMPLARY, OR CONSEQUENTIAL DAMAGES
// (INCLUDING, BUT NOT LIMITED TO, PROCUREMENT OF SUBSTITUTE GOODS OR SERVICES;
// LOSS OF USE, DATA, OR PROFITS; OR BUSINESS INTERRUPTION) HOWEVER CAUSED AND
// ON ANY THEORY OF LIABILITY, WHETHER IN CONTRACT, STRICT LIABILITY, OR TORT
// (INCLUDING NEGLIGENCE OR OTHERWISE) ARISING IN ANY WAY OUT OF THE USE OF THIS
// SOFTWARE, EVEN IF ADVISED OF THE POSSIBILITY OF SUCH DAMAGE.
//==============================================================================

#include "ublox_gps/node.h"

using namespace ublox_node;

//
// ublox_node namespace
//
uint8_t ublox_node::modelFromString(const std::string& model) {
  std::string lower = model;
  std::transform(lower.begin(), lower.end(), lower.begin(), ::tolower);
  if(lower == "portable") {
    return ublox_msgs::CfgNAV5::DYN_MODEL_PORTABLE;
  } else if(lower == "stationary") {
    return ublox_msgs::CfgNAV5::DYN_MODEL_STATIONARY;
  } else if(lower == "pedestrian") {
    return ublox_msgs::CfgNAV5::DYN_MODEL_PEDESTRIAN;
  } else if(lower == "automotive") {
    return ublox_msgs::CfgNAV5::DYN_MODEL_AUTOMOTIVE;
  } else if(lower == "sea") {
    return ublox_msgs::CfgNAV5::DYN_MODEL_SEA;
  } else if(lower == "airborne1") {
    return ublox_msgs::CfgNAV5::DYN_MODEL_AIRBORNE_1G;
  } else if(lower == "airborne2") {
    return ublox_msgs::CfgNAV5::DYN_MODEL_AIRBORNE_2G;
  } else if(lower == "airborne4") {
    return ublox_msgs::CfgNAV5::DYN_MODEL_AIRBORNE_4G;
  } else if(lower == "wristwatch") {
    return ublox_msgs::CfgNAV5::DYN_MODEL_WRIST_WATCH;
  }

  throw std::runtime_error("Invalid settings: " + lower + 
                           " is not a valid dynamic model.");
}

uint8_t ublox_node::fixModeFromString(const std::string& mode) {
  std::string lower = mode;
  std::transform(lower.begin(), lower.end(), lower.begin(), ::tolower);
  if (lower == "2d") {
    return ublox_msgs::CfgNAV5::FIX_MODE_2D_ONLY;
  } else if (lower == "3d") {
    return ublox_msgs::CfgNAV5::FIX_MODE_3D_ONLY;
  } else if (lower == "auto") {
    return ublox_msgs::CfgNAV5::FIX_MODE_AUTO;
  }

  throw std::runtime_error("Invalid settings: " + mode + 
                           " is not a valid fix mode.");
}

//
// u-blox ROS Node
//
UbloxNode::UbloxNode() {
  initialize();
}

void UbloxNode::addFirmwareInterface() {
  int ublox_version;
  if (protocol_version_ < 14) {
    components_.push_back(ComponentPtr(new UbloxFirmware6));
    ublox_version = 6;
  } else if (protocol_version_ >= 14 && protocol_version_ <= 15) {
    components_.push_back(ComponentPtr(new UbloxFirmware7));
    ublox_version = 7;
  } else {
    components_.push_back(ComponentPtr(new UbloxFirmware8));
    ublox_version = 8;
  }
  ROS_INFO("U-Blox Firmware Version: %d", ublox_version);
}


void UbloxNode::addProductInterface(std::string product_category, 
                                    std::string ref_rov) {
  if (product_category.compare("HPG") == 0 && ref_rov.compare("REF") == 0)
    components_.push_back(ComponentPtr(new UbloxHpgRef));
  else if (product_category.compare("HPG") == 0 && ref_rov.compare("ROV") == 0)
    components_.push_back(ComponentPtr(new UbloxHpgRov));
  else if (product_category.compare("TIM") == 0)
    components_.push_back(ComponentPtr(new UbloxTim));
  else if (product_category.compare("ADR") == 0 || 
           product_category.compare("UDR") == 0)
    components_.push_back(ComponentPtr(new UbloxAdrUdr));
  else if (product_category.compare("FTS") == 0)
    components_.push_back(ComponentPtr(new UbloxFts));
  else if(product_category.compare("SPG") != 0)
    ROS_WARN("Product category %s %s from MonVER message not recognized %s", 
             product_category.c_str(), ref_rov.c_str(),
             "options are HPG REF, HPG ROV, TIM, ADR, UDR, FTS, SPG");
}

void UbloxNode::getRosParams() {
  // int uart_in_default = ;
  nh->param("device", device_, std::string("/dev/ttyACM0"));
  nh->param("frame_id", frame_id, std::string("gps"));
  // UART 1 params
  getRosParam("uart1/baudrate", baudrate_, 9600);
  getRosParam("uart1/in", uart_in_, ublox_msgs::CfgPRT::PROTO_UBX 
                                    | ublox_msgs::CfgPRT::PROTO_NMEA
                                    | ublox_msgs::CfgPRT::PROTO_RTCM);
  getRosParam("uart1/out", uart_out_, ublox_msgs::CfgPRT::PROTO_UBX);
  // Measurement rate params
  nh->param("rate", rate_, 4.0);  // in Hz
  getRosParam("nav_rate", nav_rate, 1);  // # of measurement rate cycles
  // RTCM params
  getRosParam("rtcm/ids", rtcm_ids);  // RTCM output message IDs 
  getRosParam("rtcm/rates", rtcm_rates);  // RTCM output message rates
  // PPP: Advanced Setting
  nh->param("enable_ppp", enable_ppp_, false);
  // SBAS params, only for some devices
  nh->param("sbas", enable_sbas_, false);
  getRosParam("sbas/max", max_sbas_, 0); // Maximum number of SBAS channels
  getRosParam("sbas/usage", sbas_usage_, 0);
  nh->param("dynamic_model", dynamic_model_, std::string("portable"));
  nh->param("fix_mode", fix_mode_, std::string("auto"));
  getRosParam("dr_limit", dr_limit_, 0); // Dead reckoning limit

  if (enable_ppp_) 
    ROS_WARN("Warning: PPP is enabled - this is an expert setting.");

  checkMin(rate_, 0, "rate");

  if(rtcm_ids.size() != rtcm_rates.size())
    throw std::runtime_error(std::string("Invalid settings: size of rtcm_ids") +
                             " must match size of rtcm_rates");
    
  dmodel_ = modelFromString(dynamic_model_);
  fmode_ = fixModeFromString(fix_mode_);

  nh->param("dat/set", set_dat_, false);
  if(set_dat_) {
    std::vector<float> shift, rot;
    if (!nh->getParam("dat/majA", cfg_dat_.majA)
        || nh->getParam("dat/flat", cfg_dat_.flat)
        || nh->getParam("dat/shift", shift)
        || nh->getParam("dat/rot", rot)
        || nh->getParam("dat/scale", cfg_dat_.scale))
      throw std::runtime_error(std::string("dat/set is true, therefore ") +
         "dat/majA, dat/flat, dat/shift, dat/rot, & dat/scale must be set");
    if(shift.size() != 3 || rot.size() != 3)
      throw std::runtime_error(std::string("size of dat/shift & dat/rot ") +
                               "must be 3");
    checkRange(cfg_dat_.majA, 6300000.0, 6500000.0, "dat/majA");
    checkRange(cfg_dat_.flat, 0.0, 500.0, "dat/flat");
    
    checkRange(shift, 0.0, 500.0, "dat/shift");
    cfg_dat_.dX = shift[0];
    cfg_dat_.dY = shift[1];
    cfg_dat_.dZ = shift[2];
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

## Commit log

2016-03-14 Base for pozyx-driver, change to detect also MTi
2016-03-14 Reverted xsens-driver to default
    [mtdevice.py, mtnode_new.py]
2016-03-22 Fixed problem with restarting measurements, added default parameters for XSens
    [mtdevice.py]
2016-04-07 Added LED to show recording state, GPS-IMU-sync in ascii-logger
2016-04-18 Made interrupts work better at least on Minnowboard
2016-04-18 Added interrupts to Pozyx-library, speedup to i2c reading
2016-04-28 Added alignment reset to beginning of logging
    [mtdevice.py]
2016-05-04 Squashed 'nodes/pozyx/include/Pozyx-Arduino-library/' content from commit bcadfab
    git-subtree-dir: nodes/pozyx/include/Pozyx-Arduino-library
    git-subtree-split: bcadfab2e5b0cb6424808611d8cd9b447cbcf741
2016-05-04 Squashed 'nodes/pozyx/include/Userspace-Arduino/' content from commit 87772fd
    git-subtree-dir: nodes/pozyx/include/Userspace-Arduino
    git-subtree-split: 87772fd40b177cc61ed5018b4245edeff65cba7d
2016-05-18 Added 3D parts
    [assembled_sensorblock2.SLDASM, blockbase2.STL, rpibase2.STL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]
2016-06-07 Basic ROS node for Pozyx IMU-data and position
2016-06-08 initial 3d models for minnowboard and ascii_logger new README
    [assembled_sensorblock2.SLDASM, minnow_base_v3.SLDPRT, minnow_base_v3.STL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]
2016-06-21 Added led for minnowboard
2016-06-30 Shutdown switch and led fix
    [switch.cpp]
2016-07-01 Updated 3D parts
    [assembled_sensorblock2.SLDASM, blockbase2.STL, minnow_base_v3.SLDPRT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]
2016-07-01 Higher sides to minnow case 3D
    [minnow_base_v3.SLDPRT, minnow_base_v3_5.SLDPRT, minnow_blockbase_v3.SLDPRT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]
2016-07-05 Updates to LED signaling, mtdevice version for MTw
2016-07-13 Fixed issue in imu fusion
2016-07-13 Changes to kinetic, fixed imu fusion issue in ascii_logger
2016-07-15 Pozyx to show errors and grive to restart
    [Pozyx_core.cpp]
2016-07-18 Pozyx no IMU, only position and range output
2016-07-19 Fix for pozyx without imu
    [Pozyx_core.cpp]
2016-07-22 Added anchor selection and bad range filter
2016-07-26 Removed pozyx includes, added arduino to linux patch
2016-07-26 Patched Pozyx library arduino to linux
2016-07-26 Deleted old 3d files
    [minnow_base_v3.SLDPRT, minnow_base_v3.STL, minnow_blockbase_v3.SLDPRT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]
2016-07-26 Deleted unnecessary line from switch.cpp
2016-07-26 Fixed Pozyx platform selection
    [Pozyx_core.cpp]
2016-07-27 Fixes for pozyx after library updates, interrupt handler
    [Pozyx_core.cpp]
2016-08-10 Updated 3d rpi case files, removed gcodes
    [rpi_base_v1_3.SLDPRT, rpi_base_v1_4.SLDPRT, rpi_blockbase_v1_3.SLDPRT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]
2016-08-15 Fixed led-pin argument
2016-08-17 Added experimental pozyx adapter for RPi
    [pozyx_rpi_adapter_v0.3.fcstd, pozyx_rpi_adapter_v0.3.stl]
2016-08-19 Updated pozyx rpi adapter
    [pozyx_rpi_adapter_v0.3.fcstd, pozyx_rpi_adapter_v0.3.stl, pozyx_rpi_adapter_v0.4.fcstd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]
2016-08-26 Added MTw ID as frame_id
2016-09-01 Changed led settings for RPi
2016-09-01 Added experimental sync for multiple IMUs with different frame_ids
2016-10-10 Updated parse_data.py to convert frame_id's to integers for easier import to Matlab
2016-12-15 Fixed support for multiple IMUs
2017-06-15 ascii_logger: write also without imu
2017-07-25 Added new message for Imu with sequence number
2017-07-25 Modified nodes to use ImuSequenced message
2017-07-25 ascii_logger: don't delete data with overlapping fuses
2017-07-26 Fixed xsens_driver to use ImuSequenced
    [mtnode_new.py]
2017-07-27 Squashed 'nodes/ublox/' changes from 2e16119..7437b54
    7437b54 Merge pull request #18 from vmlane/master
    b2e0eb2 minor updates to readme
    dec6aec moved getRosParam template functions into node.h and used checkRange function for the getRosParam functions
    3f8e1a0 readme changes
    bac02a7 In config files, changed reset mode since it seems to work better
    ab42a9c Changed how unsigned int parameters are handled.
    e7e8bbe Added NMEA flag params for firmware version 6 and updated readme to include NMEA params.
    4132fae Renamed cfg_gnss param namespace to gnss. Fixed bug with NMEA configuration for compat variable. Added sample config file for NMEA.
    24925e5 added comments
    e39cf46 After resetting the device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
    [gps.cpp]
2017-08-01 Changed mtw to use ImuSequenced
2017-08-23 VN200 case
    [rpi_blockbase_v1_5-vn200.STL, rpi_blockbase_v1_5.SLDPRT]
2017-08-30 Modified VN200 case
    [rpi_blockbase_v1_5.SLDPRT, rpi_blockbase_v1_6-vn200.STL, rpi_blockbase_v1_6.SLDPRT]
2017-10-12 Fixed vn200 gps additions
    [vn200_node.cpp]
2017-10-31 Added support for stable red only when GPS fix 3D
    [vn200_node.cpp]
2018-01-22 Hopefully fixed stable red on GPS fix
    [vn200_node.cpp]
2018-02-12 Added new designs for case with VN200 inside
    [rpi_base_v1_7.SLDPRT, rpi_blockbase-vn200_v1_7.SLDPRT, rpi_case_assembly-vn200_v1_7.SLDASM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]
2018-02-16 Added suggested lower magnetometer velocity threshold
2018-03-07 Time update fix + green led off when no internet
2018-04-12 Datafiles to CSC, antenna position
2018-05-16 Blink green led fast for 2 secs if error starting INS
2018-07-25 Latest case files
    [rpi_base_v1_84.SLDPRT, rpi_blockbase_v1_84.SLDPRT, rpi_case_assembly_v1_84 - rpi_base_v1_83-1.STL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]
2018-07-30 GPS hole covers
    [gps-hole-cover.SLDPRT, gps-hole-cover.STL]
2021-11-01 3D files and size image of 1s dataLogger vers 2021
    [blockbase_allholes_test2.stl, rpi_case_assembly_v1_84 - rpi_lid2_v1_83-1_withhole.stl]
2022-04-13 Create IMU.ino for m5stickC plus
2022-04-13 Update and rename imu.ino to imu-test.ino
2022-07-13 1st stage so fit subject 2-8
2022-08-01 Add basic model prediction for all subjects
    [Subj1-predict.csv, Subj2-predict.csv, Subj3-predict.csv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]
2022-09-04 Add previous 1st stage sware for subject 1
2023-01-17 Add all subjects' predicted files
    [Subj-10-predict-noHR.csv, Subj-10-predict-oHR.csv, Subj-10-predict-oVel-old.csv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]
2023-01-18 All subjects prediction
    [O_10_predict_HRonly.csv, O_10_predict_noHR.csv, O_10_predict_speedOnly.csv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]
2023-02-06 Add old circuit schema
